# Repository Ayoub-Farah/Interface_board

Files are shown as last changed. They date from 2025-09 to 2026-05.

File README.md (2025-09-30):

# Obsidian

## Description

Obsidian is a FPGA carrier board in development, designed to interface with ADC and DAC devices,
either stand-alone or as an I/O expansion board for [Marble](https://github.com/BerkeleyLab/Marble).

The design files here were created with [KiCad](https://www.kicad.org/) version 9.0.0-rc3.

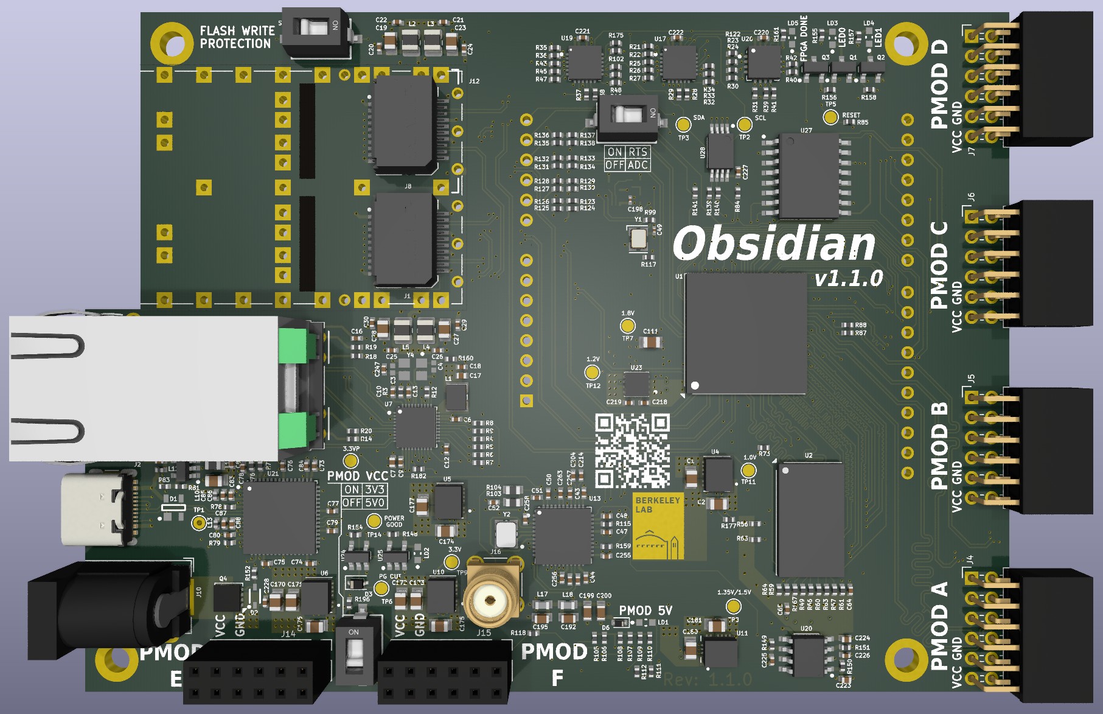
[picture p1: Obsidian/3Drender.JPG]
Obsidian


## Major Parts

- Xilinx XC7A50T-1CSG325C FPGA

## Credits

## License

---

## Project status

### Included features

- [ ] Arduino shield compatible, like the Digilent Arty
- [ ] SPI flash boot
- [ ] DDR3 memory chip
- [ ] FTDI USB interface
- [ ] 2 direct LEDs
- [ ] 1 GigE port (PoE?)
- [ ] 6 Pmod ports (3.3V)
- [ ] MS5351M or SI5351A or similar for GTP frequency reference
- [ ] USB-C (single USB cable)
- [ ] 4 x SFP
- [ ] I2C or 1-Wire chip for serial number / ROM
- [ ] White Rabbit compatibility

### High speed links

The 7A50T-1CSG325C has 4 x GTP lanes, capable of 3.75 Gbaud.
The primary use-case involves attaching one of those to a Marble over fiber.

The two MGTREFCLK signals are the direct White-Rabbit 125 MHz TCVCXO
and the configurable MS5351M output.

### Wishlist

- [ ] Standardized board size for good case options: Mini-ATX (150 x 150 mm)? Pico-ATX?

### User I/O Pins
- 48 pins for 6 x Pmod
- 49 pins for DDR3 (equivalent to Arty and Marble-Mini)
- 13 pins for RGMII (including reset pin)
- 2 Ethernet PHY MDIO
- 4 pins for White Rabbit DAC (can attach LEDs to 2 x SYNC pins?)
- 1 or more clock input (not counting MGTREFCLK)
- 2 pins for I2C
- 14 pins for Arduino digital IO
- 8 pins for Arduino 4 analog channels
- 2 pins USB UART
- 3 pins SPI flash boot (not counting CCLK in bank 0)

total 146 so far, out of 150 possible with 7A50T-1CSG325C

## Copyright

Obsidian A35 Copyright (c) 2025, The Regents of the University of California, through Lawrence Berkeley National Laboratory (subject to receipt of any required approvals from the U.S. Department of Energy). All rights reserved.

This documentation describes Obsidian A35 and is licensed under the CERN Open Hardware License v 2.0 - Permissive.

NOTICE. This documentation was developed under funding from the U.S. Department of Energy and the U.S. Government consequently retains certain rights. As such, the U.S. Government has been granted for itself and others acting on its behalf a paid-up, nonexclusive, irrevocable, worldwide license in the documentation to reproduce, distribute copies to the public, prepare derivative works, and perform publicly and display publicly, and to permit others to do so.

You may redistribute and modify this documentation under the terms of the CERN OHL v. 2.0 - Permissive (see [CERN-OHL-P-2.0](https://spdx.org/licenses/CERN-OHL-P-2.0.html) for terms and conditions). THIS DOCUMENTATION IS PROVIDED BY THE COPYRIGHT HOLDERS AND CONTRIBUTORS "AS IS" AND ANY EXPRESS OR IMPLIED WARRANTIES, INCLUDING, BUT NOT LIMITED TO, THE IMPLIED WARRANTIES OF MERCHANTABILITY AND FITNESS FOR A PARTICULAR PURPOSE ARE DISCLAIMED. IN NO EVENT SHALL THE COPYRIGHT OWNER OR CONTRIBUTORS BE LIABLE FOR ANY DIRECT, INDIRECT, INCIDENTAL, SPECIAL, EXEMPLARY, OR CONSEQUENTIAL DAMAGES (INCLUDING, BUT NOT LIMITED TO, PROCUREMENT OF SUBSTITUTE GOODS OR SERVICES; LOSS OF USE, DATA, OR PROFITS; OR BUSINESS INTERRUPTION) HOWEVER CAUSED AND ON ANY THEORY OF LIABILITY, WHETHER IN CONTRACT, STRICT LIABILITY, OR TORT (INCLUDING NEGLIGENCE OR OTHERWISE) ARISING IN ANY WAY OUT OF THE USE OF THIS SOFTWARE, EVEN IF ADVISED OF THE POSSIBILITY OF SUCH DAMAGE. Please see the CERN OHL v. 2.0 for applicable conditions.

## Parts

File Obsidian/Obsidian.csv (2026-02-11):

Id | Designator | Footprint | Quantity | Designation | Supplier and ref
1 | R156,R76,R155,R158,R81,R176,R148,R161,R157,R77,R163,R2,R98,R75 | RESC1005X40N | 14 | R0402_10K_1%_0.0625W_100PPM
2 | C13,C227,C78,C84,C10,C22,C247,C202,C74,C80,C205,C221,C225,C26,C29,C9,C88,C222,C77,C248,C86,C12,C228,C76,C226,C204,C82,C220,C75,C24,C214,C25,C21,C18,C16,C30,C79,C20,C64,C65,C6,C213,C32,C63,C34,C66,C68,C14,C40,C42,C33,C15,C31,C8,C70,C67,C41,C69,C39 | CAPC1005X55N | 59 | CC0402_100NF_50V_10%_X7R
3 | R61,R167,R63,R65,R66,R56,R64,R60,R159,R59,R49,R57,R55,R58,R54,R53,R70,R69,R71,R52,R50,R62,R67,R68,R51,R153 | RESC1005X40N | 26 | R0402_40R2_1%_0.0625W_100PPM
4 | U3 | MSOP-10_3x3mm_P0.5mm | 1 | Si5351A-B-GT
5 | R129,R137,R133,R123 | RESC1005X40N | 4 | R0402_140R_1%_0.0625W_100PPM
6 | R131,R135,R125,R127 | RESC1005X40N | 4 | R0402_2K32_1%_0.0625W_100PPM
7 | U12 | SOT95P284X122-5N | 1 | LP5951MF-3.0/NOPB
8 | C19,C177,C172,C181,C1,C28,C23,C171,C27,C170,C173,C83,C38,C36,C35,C37 | CAPC2012X135N | 16 | CC0805_22UF_16V_10%_X5R
9 | TP2,TP12,TP10,TP5,TP11,TP9,TP8,TP6,TP3,TP14,TP7,TP13,TP4 | TestPoint_Pad_D1.5mm | 13 | TestPoint
10 | R182,R28,R34,R87,R25,R32,R31,R45,R122,R44,R14,R41,R140,R85,R47,R21,R79,R18,R73,R26,R24,R30,R12,R38,R43,R39,R46,R48,R22,R37,R141,R33,R139,R35,R23,R29,R36,R40,R42,R27,R11,R15,R16,R13,R10,R86,R17 | RESC1005X40N | 47 | R0402_4K7_1%_0.0625W_100PPM
11 | R19,R20 | RESC1005X40N | 2 | R0402_330R_1%_0.0625W_100PPM
12 | U16 | QFN50P500X500X100-33N-S355 | 1 | CDCM61004RHB
13 | C209,C191,C208,C198,C185,C196,C194,C189,C212,C183,C210,C215,C190,C206,C197,C211,C165,C249,C154,C250,C166,C164,C159,C186,C169,C158,C163,C157,C160 | CAPC0603X33N | 29 | CC0201_100NF_6.3V_10%_X5R
14 | L17,L18,L20 | INDC1608X65N | 3 | IND0603_MURATA_BLM18SG121TN1D
15 | C199,C201,C192,C200,C203,C195,C187 | CAPC1709X100N | 7 | CC0603_22UF_6.3V_20%_X5R
16 | C188 | CAPC1005X55N | 1 | CC0201_100NF_6.3V_10%_X5R
17 | J6,J4,J5,J7 | PinSocket_2x06_P2.54mm_Horizontal_PMOD | 4 | Conn_02x06_Top_Bottom
18 | C218,C85,C87,C73,C81,C219,C103,C108,C168,C123,C131,C118,C105,C167,C161,C107,C142,C104,C106,C133,C162,C61,C156,C132,C141,C117 | CAPC1005X55N | 26 | CC0402_4.7UF_16V_20%_X5R
19 | R113,R116 | RESC1005X40N | 2 | R0402_510R_0.1%_0.0625W_10PPM
20 | L3,L5,L2,L4,L8,L9,L6,L7 | L_1008_2520Metric | 8 | 4.7 uH
21 | R150,R132,R136,R151,R84,R89,R128,R126,R149,R88,R90 | RESC1005X40N | 11 | R0402_1K_1%_0.0625W_100PPM
22 | U18 | SOT-23-5 | 1 | TLV77325PDBVR
23 | U11,U4,U10,U5,U6 | VREG_TPSM863257RDXR | 5 | TPSM863257RDXR
24 | C3,C4,C72,C71 | CAPC1005X55N | 4 | CC0402_27PF_50V_5%_C0G
25 | R175,R154,R174,R173,R171,R165,R170,R172,R164,R166 | RESC1005X40N | 10 | R0402_100K_1%_0.0625W_100PPM
26 | U19,U17 | QFN50P400X400X80-25N-S245 | 2 | TCA9535RTWR
27 | Q2,Q3,Q1 | SOT95P240X110-3N | 3 | BSS138LT1G
28 | Y2 | OSCCC320X500X160-4N | 1 | VM53S3-25.000-2.5/-30+75
29 | R147,R162,R146,R145,R144,R95,R97,R92,R100,R142,R93,R96,R143,R101 | RESC1005X40N | 14 | R0402_30K_1%_0.0625W_100PPM
30 | C2,C174,C176,C180,C175 | CAPC2012X95N | 5 | CC0805_10UF_25V_10%_X5R
31 | R102,R121,R99,R103,R120,R72 | RESC1005X40N | 6 | R0402_240R_1%_0.0625W_100PPM
32 | C193 | CAPC1005X55N | 1 | CC0402_2.2NF_50V_10%_X7R
33 | R8,R4,R6,R7,R9,R5 | RESC1005X40N | 6 | R0402_22R_1%_0.0625W_100PPM
34 | R124,R134,R138,R130 | RESC1005X40N | 4 | R0402_845R_0.1%_0.063W_25PPM
35 | C207,C182,C184,C216,C217 | CAPC1005X55N | 5 | CC0402_1UF_16V_10%_X5R
36 | J2 | USB_C_Receptacle_GCT_USB4105-xx-A_16P_TopMnt_Horizontal | 1 | USB_C_Receptacle_USB2.0_16P
37 | D1 | SOT190P230X110-4N | 1 | PRTR5V0U2X
38 | R78,R152,R177,R180,R178,R169,R179,R181 | RESC1005X40N | 8 | R0402_12K_1%_0.0625W_100PPM
39 | B3,B1,B4,B2 | MTG320_550 | 4 | PLATED_HOLE3.2_PAD5.5
40 | R105,R106,R110,R160,R104,R107,R112,R108,R111,R109 | RESC1005X40N | 10 | R0402_0R_JUMPER
41 | C7,C17,C223,C224,C5,C151,C152,C62,C11 | CAPC1005X70N | 9 | CC0402_10UF_6.3V_20%_X5R
42 | Y6 | XTAL_TXC_8Y | 1 | XTAL_25MHZ_TXC_8Y-25.000MAAJ-T
43 | C111,C122,C119,C110,C109 | CAPC2012X145N | 5 | CC0805_100UF_6.3V_20%_X5R
44 | U25,U24 | SOT95P280X145-5N | 2 | SN74LVC1G07DBV
45 | LD1 | LED_OSRAM_LS Q976 | 1 | LED_OSRAM_LS_Q976-NR-1
46 | U21 | QFN50P900X900X100-65N-S445 | 1 | FT2232HQ
47 | R118,R119 | RESC1005X40N | 2 | R0402_200R_1%_0.0625W_100PPM
48 | R83,R74 | RESC1005X40N | 2 | R0402_2K2_1%_0.0625W_100PPM
49 | D2 | SODFL2513X100N | 1 | MM3Z12VB
50 | SW2,SW1 | SW_OMRON_A6SN-1101 | 2 | SW_DIP_x01
51 | U28 | SOP65P640X120-8N | 1 | 24AA256UID-I_ST
52 | J14,J15 | PinSocket_2x06_P2.54mm_Vertical_PMOD | 2 | Conn_02x06_Top_Bottom
53 | R82,R80 | RESC1005X40N | 2 | R0402_5K1_1%_0.0625W_100PPM
54 | J8,J9 | TE_2180739-1 | 2 | 2180739-1
55 | U8 | SOT95P280X145-5N | 1 | TLV62565DBV
56 | Q4 | Diodes_PowerDI3333-8 | 1 | DMP3013SFV
57 | R117,R115,R114 | RESC1005X40N | 3 | R0402_100R_1%_0.1W_100PPM
58 | U14,U15 | SOP65P490X110-8N | 2 | DAC8550IDGK
59 | J1,J11 | TYCO_1367073-1 | 2 | TYCO_1888247-1
60 | Y3 | OSC_IQD_CFPV-45 | 1 | OSC_20MHZ_IQD_LFVCXO026156
61 | U26 | QFN65P400X400X100-17N-S225 | 1 | PCA9546ARGV
62 | U2 | FBGA-96_8x14mm_Layout9x16_P0.8mm | 1 | MT41K512M16HA-125_E / MT41K512M16VRP-107 IT:P
63 | U13 | SOIC127P600X175-8N | 1 | LM336M-2.5
64 | L10,L13,L12 | INDC1005X55N | 3 | IND0402_MURATA_BLM15PX121SN1D
65 | LD2,LD3,LD5,LD4 | LED_KINGBRIGHT_KPH-1608CGCK | 4 | LED_KINGBRIGHT_KPH-1608CGCK
66 | L14 | IND_WURTH_WE-PMCI_0806LR | 1 | IND_2.2UH_20%_WURTH_WE-PMCI_74479276222C
67 | J3 | BEL_0826-1G1T-43-F | 1 | BELFUSE_0826-1G1T-43-F
68 | U23 | SON65P300X300X100-9N-R170X245 | 1 | NCV59801CML120TCG
69 | D3 | D_SOD-323 | 1 | BAS316
70 | U1 | Xilinx_CSG325 | 1 | XC7A35T-CSG325
71 | A1 | Arduino_UNO_R3 | 1 | Arduino_UNO_R3
72 | Y4 | XTAL_EPSON_TSX-3225 | 1 | XTAL_25MHZ_EPSON_TSX-3225_25.0000MF10Z-AC
73 | U27 | SOIC127P1030X265-16N | 1 | S25FL128SAGMFI001
74 | U20 | SOIC127P600X168-9N-S230 | 1 | RT9045AGSP / AP2303
75 | L1 | IND_BOURNS_SRP3212 | 1 | IND_2.2UH_20%_BOURNS_SRP3212
76 | U7 | QFN40P500X500X80-41N-S360 | 1 | RTL8211F-CG
77 | R3 | RESC1005X40N | 1 | R0402_2K49_1%_0.063W_100PPM
78 | TP1 | TestPoint_THTPad_D1.5mm_Drill0.7mm | 1 | TestPoint
79 | J10 | BarrelJack_GCT_DCJ200-10-A_Horizontal | 1 | Barrel_Jack_Switch
80 | J12,J13 | TYCO_1888247-1 | 2 | TYCO_1888247-1
81 | C95,C126,C245,C94,C92,C153,C120,C90,C144,C137,C134,C124,C145,C115,C143,C89,C96,C136,C146,C91,C246,C125,C135,C113,C93,C155,C116,C114,C127 | CAPC0603X33N | 29 | CC0201_470NF_4V_20%_X5R
82 | C240,C244,C121,C139,C230,C100,C128,C236,C239,C235,C130,C138,C232,C148,C242,C238,C147,C149,C233,C129,C99,C229,C97,C243,C98,C231,C102,C237,C241,C101,C140,C112,C150,C234 | CAPC0603X33N | 34 | CC0201_47NF_6.3V_10%_X5R
83 | L16 | INDC1005X55N | 1 | IND0402_MURATA_BLM15HB221SN1
84 | R1 | RESC1608X55N | 1 | R0603_6K65_0.1%_0.063W_10PPM
85 | L15 | INDC2013X145N | 1 | IND0805_TDK_MLZ2012M150WT000
86 | U22 | SOIC127P600X175-8N | 1 | 93C46B-I_SN
87 | U9 | SOT-23 | 1 | REF3012
88 | C179,C178 | CAPC1005X55N | 2 | CC0402_22PF_50V_5%_C0G
89 | R168 | RESC1005X40N | 1 | R0402_80R6_1%_0.1W_100PPM
90 | R91,R94 | RESC2012X60N | 2 | R0805_135K_0.1%_0.1W_25PPM_KOA_RN73R2ATTD1353B25
91 | Y5 | XTAL_TXC_7A | 1 | XTAL_12MHZ_TXC_7A-12.000MAAJ-T
92 | L11 | INDC1608X95N | 1 | IND0603_MURATA_BLM18AG601SN1
93 | Y1 | OSC_ABRACON_ASEMPC | 1 | OSC_25MHZ_RAKON_IVT3205CR

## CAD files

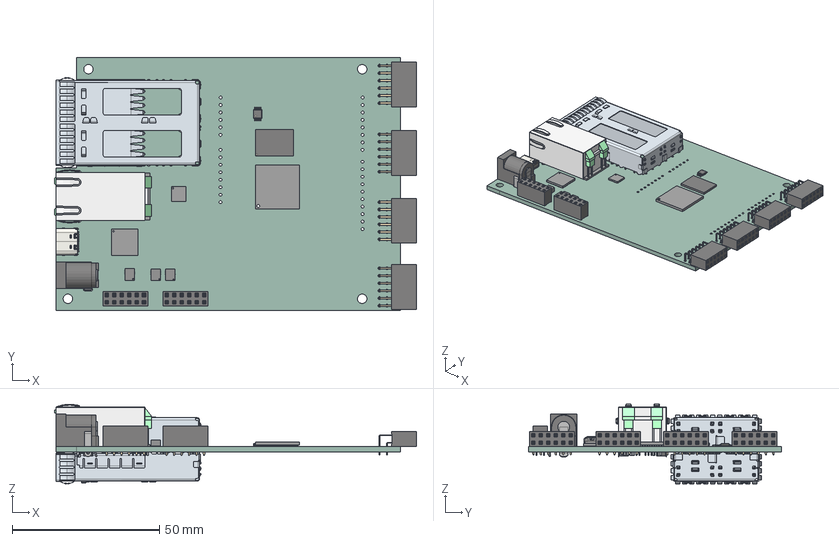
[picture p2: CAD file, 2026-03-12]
Obsidian/Obsidian.step
123.0 x 86.0 x 27.0 mm
MSOP-10_3x3mm_P0.5mm
PinSocket_2x06_P2.54mm_Horizontal x 4
USB_C_Receptacle_GCT_USB4105-xx-A_16P_TopMnt_Horizontal
QFN50P900X900X100-65N-S445
kicad_embedded_953FA939E6CC6517DF7ED2E297E245B9 x 3
PinSocket_2x06_P2.54mm_Vertical x 2
kicad_embedded_1A2E63AEB301535E0CE7C40C940B3B74 x 2
BGA-96_9.0x13.0mm_Layout2x3x16_P0.8mm
BGA324C80P18X18_1500X1500X150
QFN40P500X500X80-41N-S360
BarrelJack_GCT_DCJ200-10-A_Horizontal x 2
Marble_Tiny_PCB

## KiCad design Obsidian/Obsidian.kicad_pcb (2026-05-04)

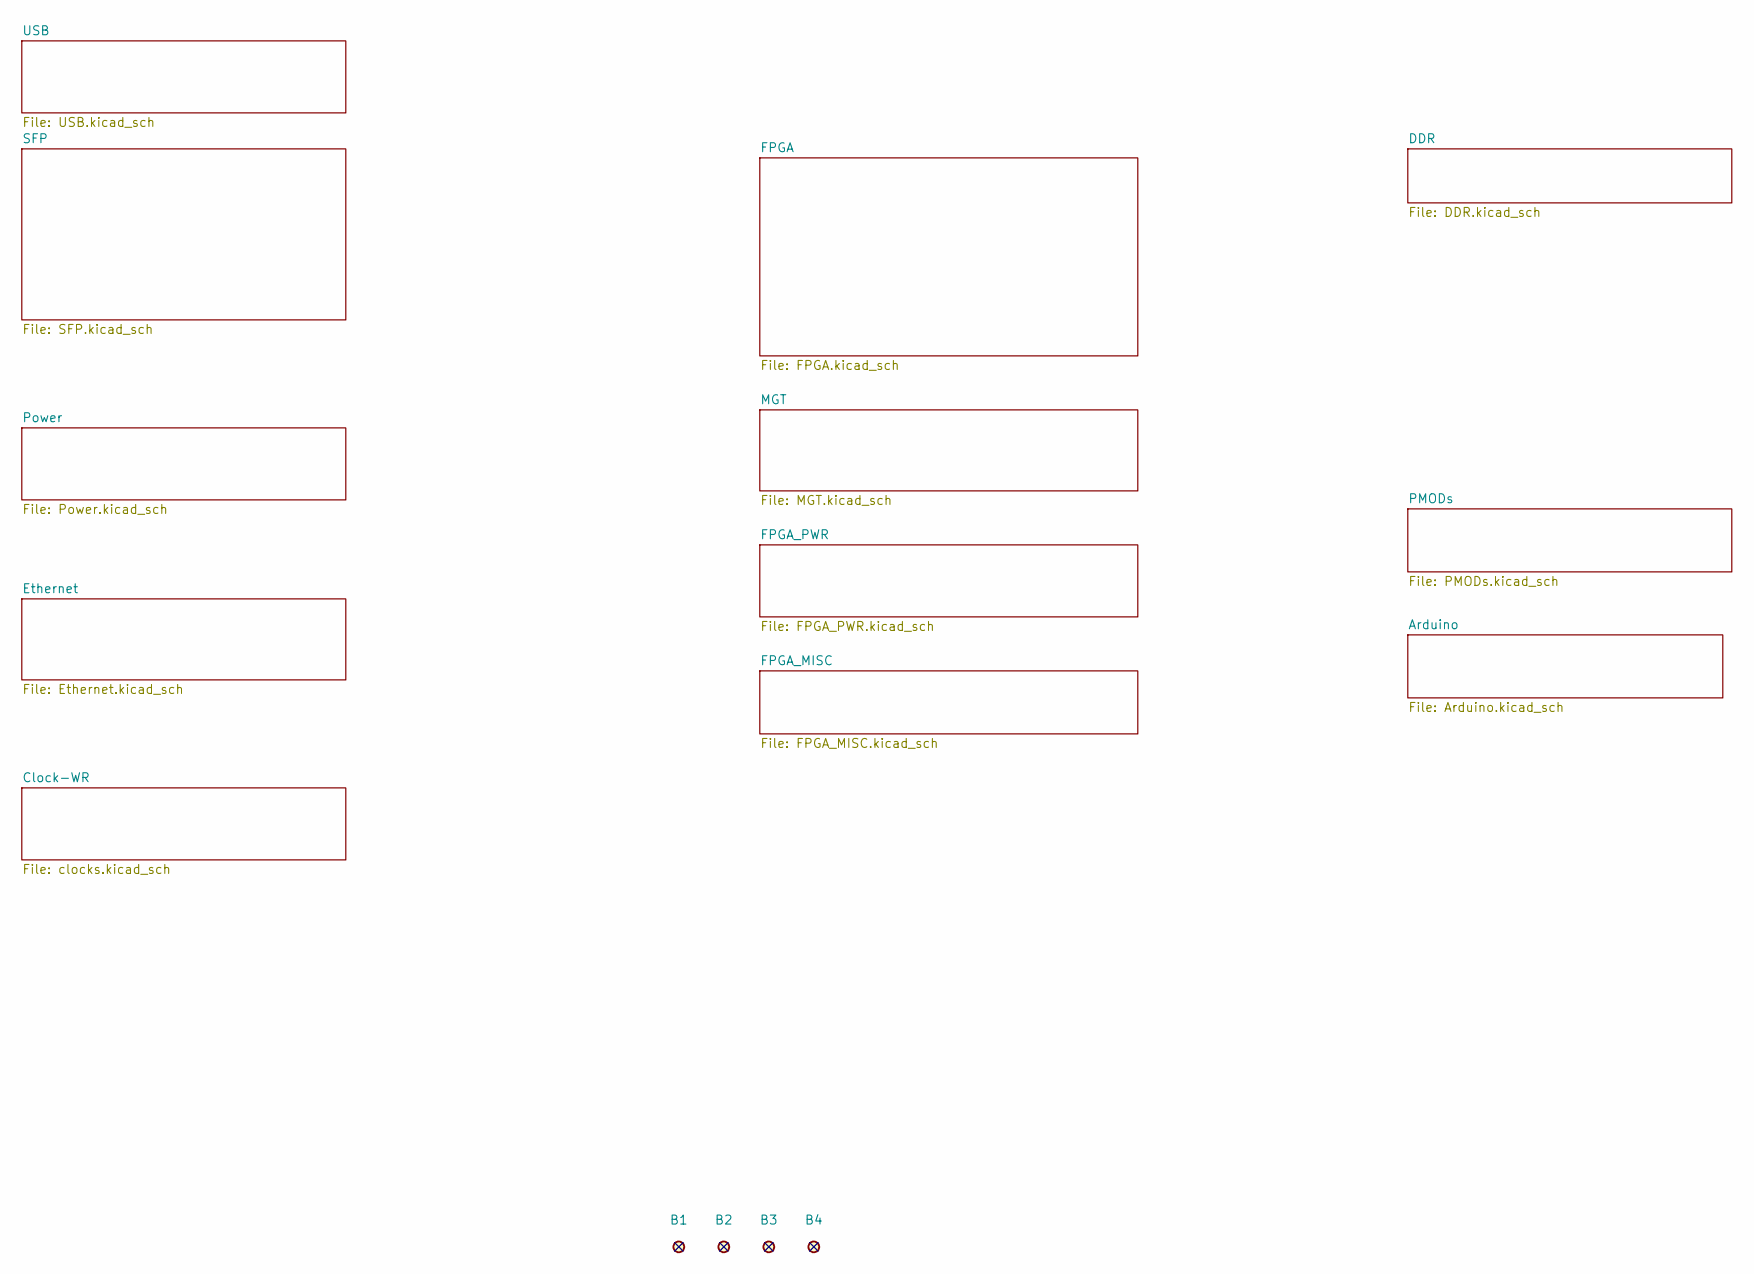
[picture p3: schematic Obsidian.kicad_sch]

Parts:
B1, B2, B3, B4: PLATED_HOLE3.2_PAD5.5; MTG320_550; Part Number PLATED_HOLE3.2_PAD5.5

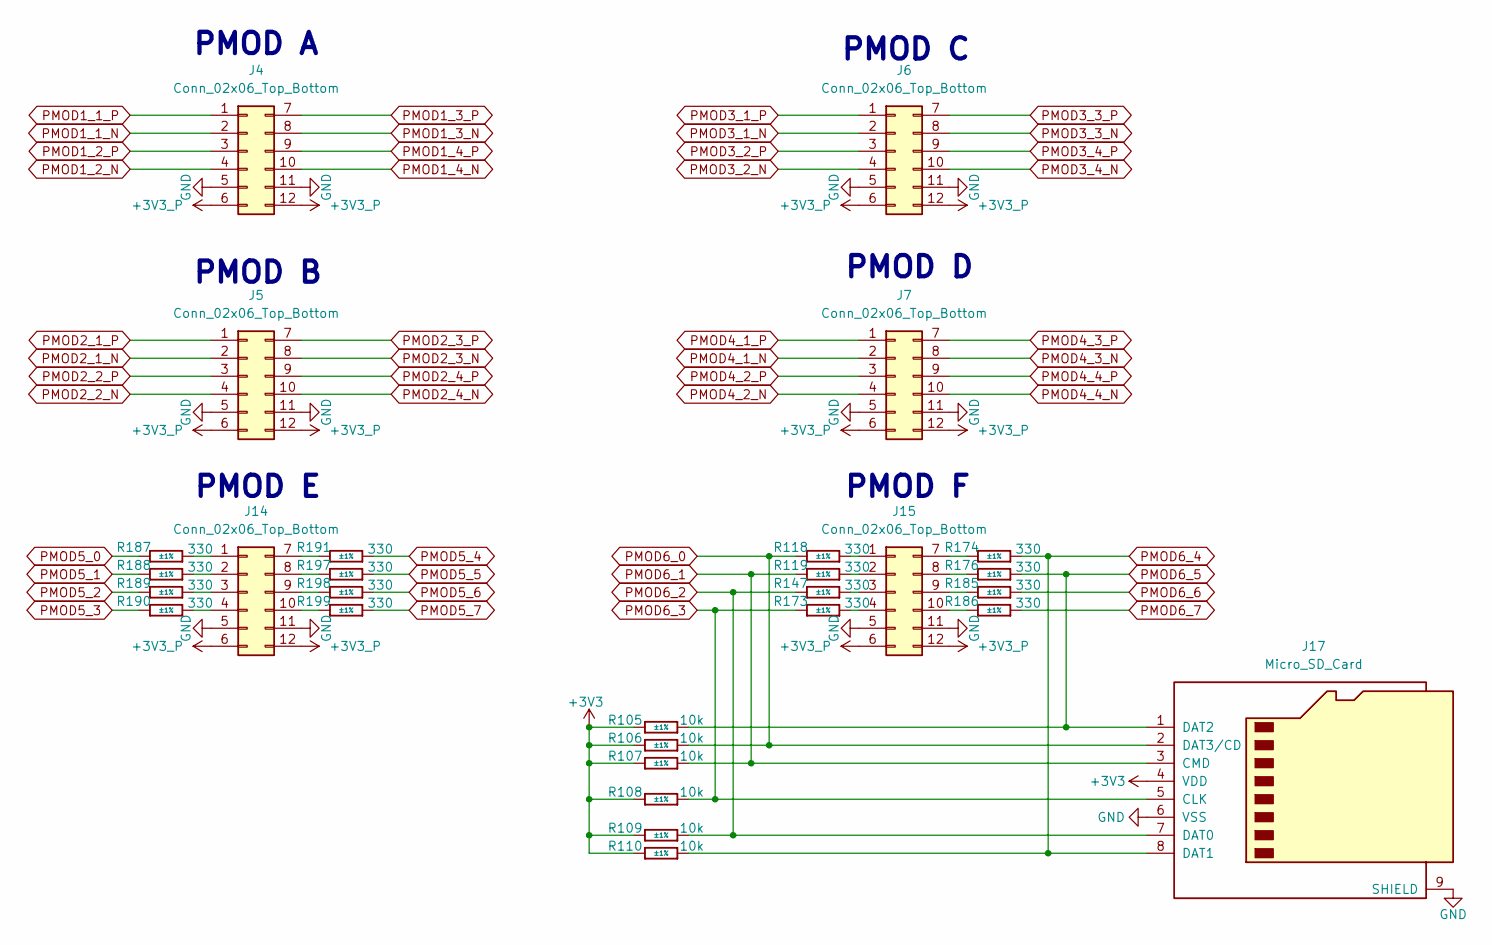
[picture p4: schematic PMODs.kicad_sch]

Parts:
J4, J5, J6, J7: Conn_02x06_Top_Bottom; PinSocket_2x06_P2.54mm_Horizontal_PMOD
J14, J15: Conn_02x06_Top_Bottom; PinSocket_2x06_P2.54mm_Vertical_PMOD
J17: Micro_SD_Card; microSD_HC_Molex_47219-2001
R105, R106, R107, R108, R109, R110: R0402_10K_1%_0.0625W_100PPM; RESC1005X40N; Tolerance ±1%; Part Number R0402_10K_1%_0.0625W_100PPM
R118, R119, R147, R173, R174, R176, R185, R186, R187, R188, R189, R190, R191, R197, R198, R199: R0402_330R_1%_0.0625W_100PPM; RESC1005X40N; Tolerance ±1%; Part Number R0402_330R_1%_0.0625W_100PPM

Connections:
+3V3: J17.4 (VDD), R105.1, R106.1, R107.1, R108.1, R109.1, R110.1; also elsewhere on the board
+3V3_P: J4.6, J4.12, J5.6, J5.12, J6.6, J6.12, J7.6, J7.12, J14.6, J14.12, J15.6, J15.12; also elsewhere on the board
GND: J4.5, J4.11, J5.5, J5.11, J6.5, J6.11, J7.5, J7.11, J14.5, J14.11, J15.5, J15.11, J17.6 (VSS), J17.9 (SHIELD); also elsewhere on the board
unnamed: J14.1, R187.2
unnamed: J14.2, R188.2
unnamed: J14.3, R189.2
unnamed: J14.4, R190.2
unnamed: J14.7, R191.1
unnamed: J14.8, R197.1
unnamed: J14.9, R198.1
unnamed: J14.10, R199.1
unnamed: J15.1, R118.2
unnamed: J15.2, R119.2
unnamed: J15.3, R147.2
unnamed: J15.4, R173.2
unnamed: J15.7, R174.1
unnamed: J15.8, R176.1
unnamed: J15.9, R185.1
unnamed: J15.10, R186.1
PMOD1_1_N: J4.2; also elsewhere on the board
PMOD1_1_P: J4.1; also elsewhere on the board
PMOD1_2_N: J4.4; also elsewhere on the board
PMOD1_2_P: J4.3; also elsewhere on the board
PMOD1_3_N: J4.8; also elsewhere on the board
PMOD1_3_P: J4.7; also elsewhere on the board
PMOD1_4_N: J4.10; also elsewhere on the board
PMOD1_4_P: J4.9; also elsewhere on the board
PMOD2_1_N: J5.2; also elsewhere on the board
PMOD2_1_P: J5.1; also elsewhere on the board
PMOD2_2_N: J5.4; also elsewhere on the board
PMOD2_2_P: J5.3; also elsewhere on the board
PMOD2_3_N: J5.8; also elsewhere on the board
PMOD2_3_P: J5.7; also elsewhere on the board
PMOD2_4_N: J5.10; also elsewhere on the board
PMOD2_4_P: J5.9; also elsewhere on the board
PMOD3_1_N: J6.2; also elsewhere on the board
PMOD3_1_P: J6.1; also elsewhere on the board
PMOD3_2_N: J6.4; also elsewhere on the board
PMOD3_2_P: J6.3; also elsewhere on the board
PMOD3_3_N: J6.8; also elsewhere on the board
PMOD3_3_P: J6.7; also elsewhere on the board
PMOD3_4_N: J6.10; also elsewhere on the board
PMOD3_4_P: J6.9; also elsewhere on the board
PMOD4_1_N: J7.2; also elsewhere on the board
PMOD4_1_P: J7.1; also elsewhere on the board
PMOD4_2_N: J7.4; also elsewhere on the board
PMOD4_2_P: J7.3; also elsewhere on the board
PMOD4_3_N: J7.8; also elsewhere on the board
PMOD4_3_P: J7.7; also elsewhere on the board
PMOD4_4_N: J7.10; also elsewhere on the board
PMOD4_4_P: J7.9; also elsewhere on the board
PMOD5_0: R187.1; also elsewhere on the board
PMOD5_1: R188.1; also elsewhere on the board
PMOD5_2: R189.1; also elsewhere on the board
PMOD5_3: R190.1; also elsewhere on the board
PMOD5_4: R191.2; also elsewhere on the board
PMOD5_5: R197.2; also elsewhere on the board
PMOD5_6: R198.2; also elsewhere on the board
PMOD5_7: R199.2; also elsewhere on the board
PMOD6_0: J17.2 (DAT3/CD), R106.2, R118.1; also elsewhere on the board
PMOD6_1: J17.3 (CMD), R107.2, R119.1; also elsewhere on the board
PMOD6_2: J17.7 (DAT0), R109.2, R147.1; also elsewhere on the board
PMOD6_3: J17.5 (CLK), R108.2, R173.1; also elsewhere on the board
PMOD6_4: J17.8 (DAT1), R110.2, R174.2; also elsewhere on the board
PMOD6_5: J17.1 (DAT2), R105.2, R176.2; also elsewhere on the board
PMOD6_6: R185.2; also elsewhere on the board
PMOD6_7: R186.2; also elsewhere on the board

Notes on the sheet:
PMOD F
PMOD E
PMOD C
PMOD A
PMOD B
PMOD D

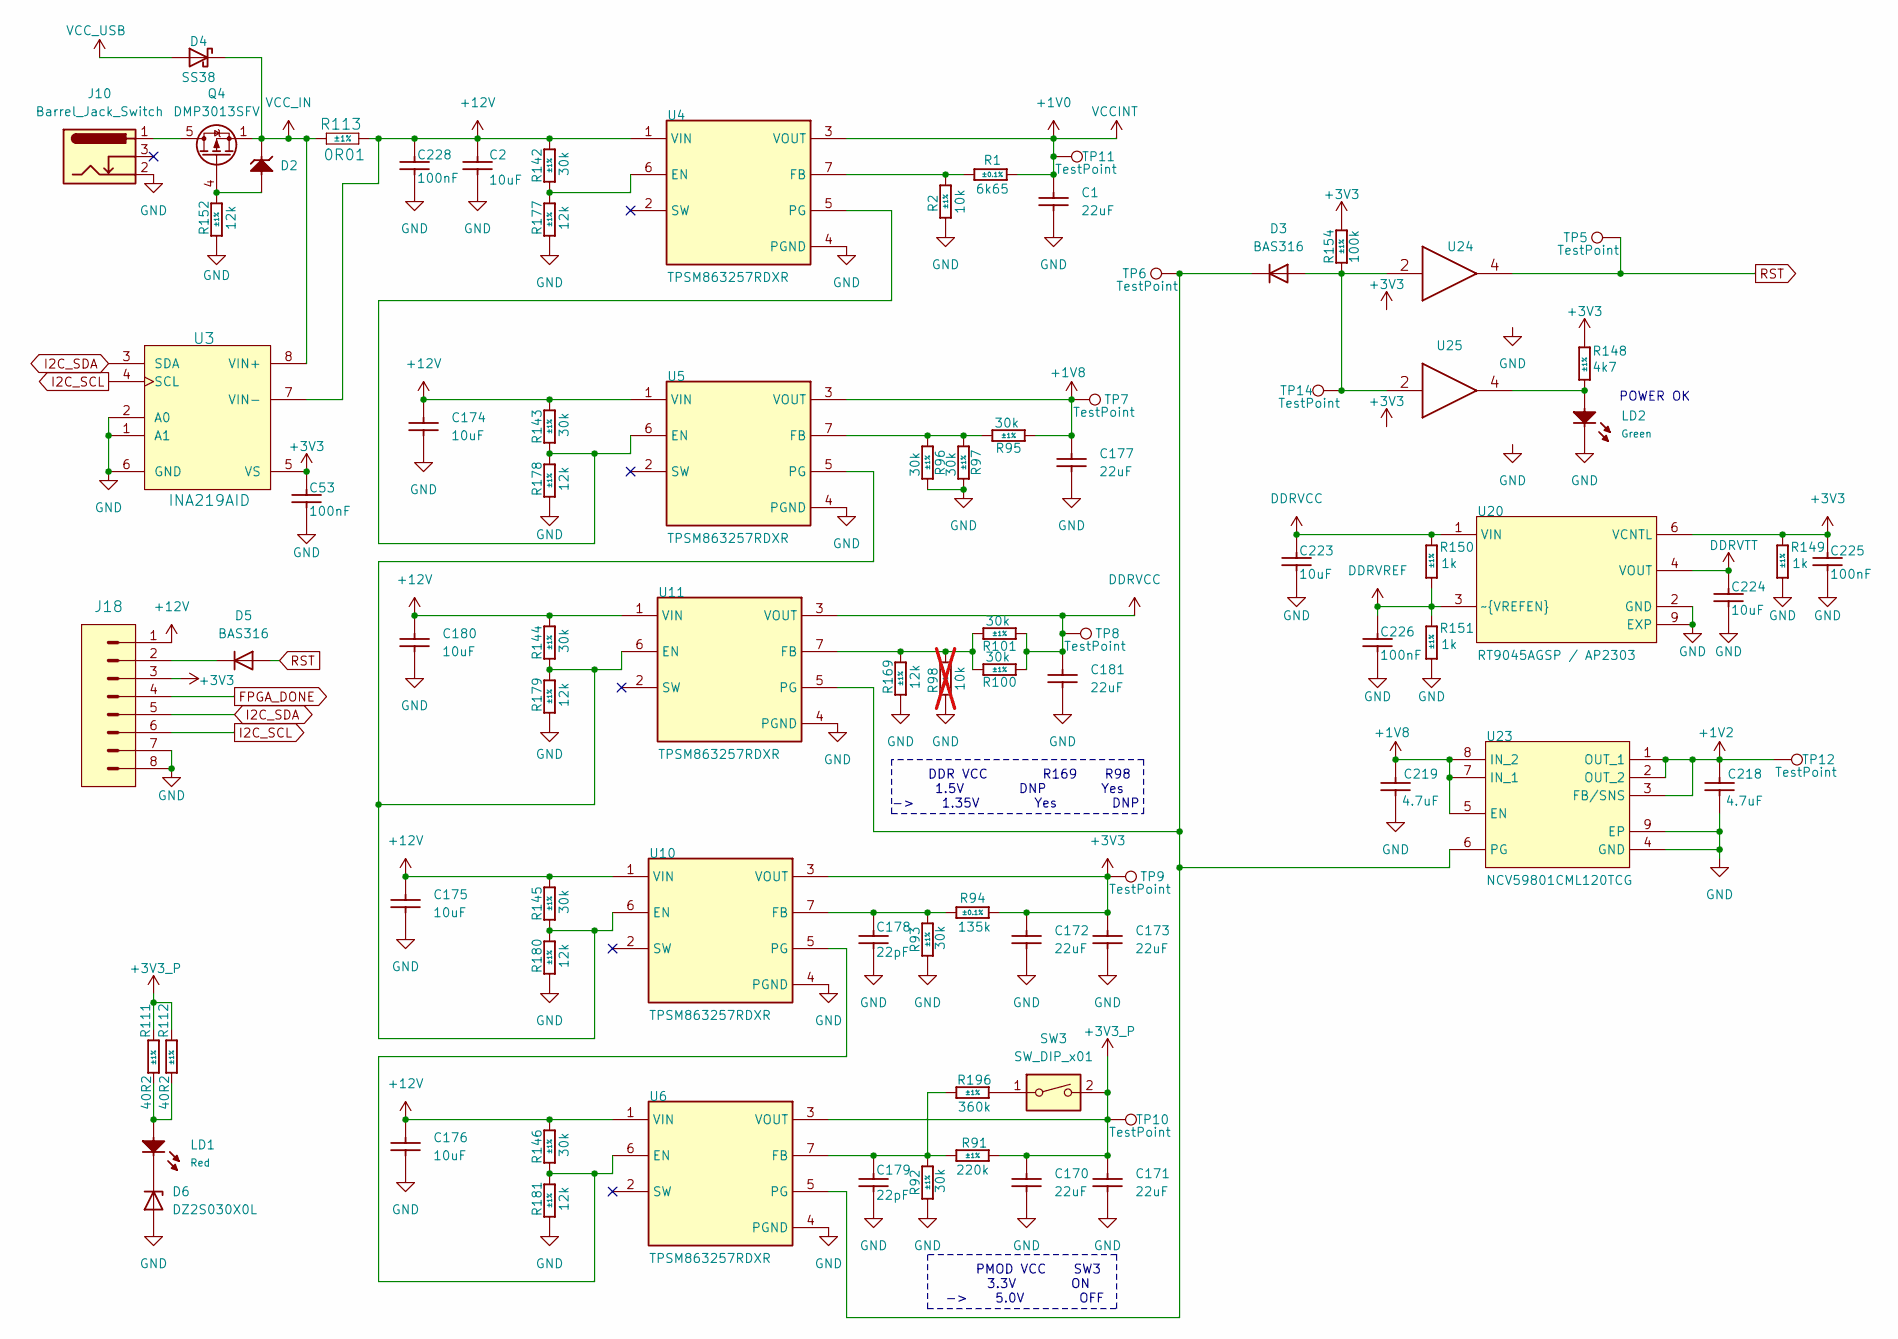
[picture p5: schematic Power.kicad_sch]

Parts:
C1, C170, C171, C172, C173, C177, C181: CC0805_22UF_16V_10%_X5R; CAPC2012X135N; Voltage 16V; Tolerance ±10%; Part Number CC0805_22UF_16V_10%_X5R
C2, C174, C175, C176, C180: CC0805_10UF_25V_10%_X5R; CAPC2012X95N; Voltage 25V; Tolerance ±10%; Part Number CC0805_10UF_25V_10%_X5R
C53, C225, C226, C228: CC0402_100NF_50V_10%_X7R; CAPC1005X55N; Voltage 50V; Tolerance ±10%; Part Number CC0402_100NF_50V_10%_X7R
C178, C179: CC0402_22PF_50V_5%_C0G; CAPC1005X55N; Voltage 50V; Tolerance ±5%; Part Number CC0402_22PF_50V_5%_C0G
C218, C219: CC0402_4.7UF_16V_20%_X5R; CAPC1005X55N; Voltage 16V; Tolerance ±20%; Part Number CC0402_4.7UF_16V_20%_X5R
C223, C224: CC0402_10UF_6.3V_20%_X5R; CAPC1005X70N; Voltage 6.3V; Tolerance ±10%; Part Number CC0402_10UF_6.3V_20%_X5R
D2: MM3Z12VB; SODFL2513X100N; Voltage 12V; Part Number MM3Z12VB
D3, D5: BAS316; D_SOD-323
D4: SS38; D_SMA
D6: DZ2S030X0L; D_SOD-523
J10: Barrel_Jack_Switch; BarrelJack_GCT_DCJ200-10-A_Horizontal
J18: Header 8; WURTH_61300821121; Part Number WURTH_61300821121
LD1, LD2: LED_KINGBRIGHT_KPH-1608CGCK; Part Number LED_KINGBRIGHT_KPH-1608CGCK
Q4: DMP3013SFV; Diodes_PowerDI3333-8
R1: R0603_6K65_0.1%_0.063W_10PPM; RESC1608X55N; Tolerance ±0.1%; Part Number R0603_6K65_0.1%_0.063W_10PPM
R2: R0402_10K_1%_0.0625W_100PPM; RESC1005X40N; Tolerance ±1%; Part Number R0402_10K_1%_0.0625W_100PPM
R91: R0402_220K_1%_0.0625W_100PPM; RESC1005X40N; Tolerance ±1%; Part Number R0402_220K_1%_0.0625W_100PPM
R92, R93, R95, R96, R97, R100, R101, R142, R143, R144, R145, R146: R0402_30K_1%_0.0625W_100PPM; RESC1005X40N; Tolerance ±1%; Part Number R0402_30K_1%_0.0625W_100PPM
R94: R0805_135K_0.1%_0.1W_25PPM_KOA_RN73R2ATTD1353B25; RESC2012X60N; Tolerance ±0.1%; Part Number R0805_135K_0.1%_0.1W_25PPM_KOA_RN73R2AT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
R98: R0402_10K_1%_0.0625W_100PPM; RESC1005X40N; Tolerance ±1%; Part Number R0402_10K_1%_0.0625W_100PPM; not fitted
R111, R112: R0402_40R2_1%_0.0625W_100PPM; RESC1005X40N; Tolerance ±1%; Part Number R0402_40R2_1%_0.0625W_100PPM
R113: 0R01; RESC3216X65N; Tolerance ±1%; Part Number R1206_0R01_1%_1W_100PPM
R148: R0402_4K7_1%_0.0625W_100PPM; RESC1005X40N; Tolerance ±1%; Part Number R0402_4K7_1%_0.0625W_100PPM
R149, R150, R151: R0402_1K_1%_0.0625W_100PPM; RESC1005X40N; Tolerance ±1%; Part Number R0402_1K_1%_0.0625W_100PPM
R152, R169, R177, R178, R179, R180, R181: R0402_12K_1%_0.0625W_100PPM; RESC1005X40N; Tolerance ±1%; Part Number R0402_12K_1%_0.0625W_100PPM
R154: R0402_100K_1%_0.0625W_100PPM; RESC1005X40N; Tolerance ±1%; Part Number R0402_100K_1%_0.0625W_100PPM
R196: R0402_360K_1%_0.0625W_100PPM; RESC1005X40N; Tolerance ±1%; Part Number R0402_360K_1%_0.0625W_100PPM
SW3: SW_DIP_x01; SW_OMRON_A6SN-1101
TP5, TP6, TP7, TP8, TP9, TP10, TP11, TP12, TP14: TestPoint; TestPoint_Pad_D1.5mm
U3: INA219AID; SOIC127P600X175-8N; Part Number INA219AID
U4, U5, U6, U10, U11: TPSM863257RDXR; VREG_TPSM863257RDXR
U20: RT9045AGSP / AP2303; SOIC127P600X168-9N-S230
U23: NCV59801CML120TCG; SON65P300X300X100-9N-R170X245; MANUFACTURER_PART_NUMBER NCV59801CML120TCG; MOUSER PART NUMBER *
U24, U25: SN74LVC1G07DBV; SOT95P280X145-5N; Part Number SN74LVC1G07DBV

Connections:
+1V0: C1.2, R1.2, TP11.1, U4.3 (VOUT); also elsewhere on the board
+1V2: C218.2, TP12.1, U23.1 (OUT_1), U23.2 (OUT_2), U23.3 (FB/SNS); also elsewhere on the board
+1V8: C177.2, C219.2, R95.2, TP7.1, U5.3 (VOUT), U23.5 (EN), U23.7 (IN_1), U23.8 (IN_2); also elsewhere on the board
+3V3: C53.2, C172.2, C173.2, C225.2, J18.3, R94.1, R148.2, R149.2, R154.1, TP9.1, U3.5 (VS), U10.3 (VOUT), U20.6 (VCNTL), U24.5 (VCC), U25.5 (VCC); also elsewhere on the board
+3V3_P: C170.2, C171.2, R91.2, R111.2, R112.2, SW3.2, TP10.1, U6.3 (VOUT); also elsewhere on the board
+12V: C2.2, C174.2, C175.2, C176.2, C180.2, C228.2, J18.1, R113.2, R142.2, R143.2, R144.2, R145.2, R146.2, U3.7 (VIN-), U4.1 (VIN), U5.1 (VIN), U6.1 (VIN), U10.1 (VIN), U11.1 (VIN); also elsewhere on the board
DDRVCC: C181.2, C223.2, R100.2, R101.2, R150.2, TP8.1, U11.3 (VOUT), U20.1 (VIN); also elsewhere on the board
DDRVREF: C226.2, R150.1, R151.2, U20.3 (~VREFEN~{}); also elsewhere on the board
DDRVTT: C224.2, U20.4 (VOUT); also elsewhere on the board
FPGA_DONE: J18.4; also elsewhere on the board
GND: C1.1, C2.1, C53.1, C170.1, C171.1, C172.1, C173.1, C174.1, C175.1, C176.1, C177.1, C178.1, C179.1, C180.1, C181.1, C218.1, C219.1, C223.1, C224.1, C225.1, C226.1, C228.1, D6.2 (A), J10.2, J18.7, J18.8, LD2.1 (C), R2.1, R92.2, R93.2, R96.1, R97.1, R98.1, R149.1, R151.1, R152.1, R169.1, R177.1, R178.1, R179.1, R180.1, R181.1, U3.1 (A1), U3.2 (A0), U3.6 (GND), U4.4 (PGND), U5.4 (PGND), U6.4 (PGND), U10.4 (PGND), U11.4 (PGND), U20.2 (GND), U20.9 (EXP), U23.4 (GND), U23.9 (EP), U24.3 (GND), U25.3 (GND); also elsewhere on the board
I2C_SCL: J18.6, U3.4 (SCL); also elsewhere on the board
I2C_SDA: J18.5, U3.3 (SDA); also elsewhere on the board
unnamed: D2.2 (A), Q4.4 (G), R152.2
unnamed: D3.2 (A), R154.2, TP14.1, U24.2 (IN), U25.2 (IN)
unnamed: D3.1 (K), TP6.1, U6.5 (PG), U11.5 (PG), U23.6 (PG)
unnamed: D5.1 (K), J18.2
unnamed: D6.1 (K), LD1.1 (C)
unnamed: LD1.2 (A), R111.1, R112.1
unnamed: LD2.2 (A), R148.1, U25.4 (OUT)
unnamed: J10.1, Q4.5 (D)
unnamed: R196.2, SW3.1
unnamed: R142.1, R177.2, U4.6 (EN)
unnamed: R1.1, R2.2, U4.7 (FB)
unnamed: R143.1, R178.2, U4.5 (PG), U5.6 (EN)
unnamed: R95.1, R96.2, R97.2, U5.7 (FB)
unnamed: C179.2, R91.1, R92.1, R196.1, U6.7 (FB)
unnamed: R144.1, R145.1, R179.2, R180.2, U5.5 (PG), U10.6 (EN), U11.6 (EN)
unnamed: C178.2, R93.1, R94.2, U10.7 (FB)
unnamed: R146.1, R181.2, U6.6 (EN), U10.5 (PG)
unnamed: R98.2, R100.1, R101.1, R169.2, U11.7 (FB)
RST: D5.2 (A), TP5.1, U24.4 (OUT); also elsewhere on the board
VCC_IN: D2.1 (C), D4.1 (K), Q4.1 (S), Q4.2 (S), Q4.3 (S), R113.1, U3.8 (VIN+)
VCC_USB: D4.2 (A); also elsewhere on the board

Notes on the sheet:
DDR VCC R169 R98 1.5V DNP Yes -> 1.35V Yes DNP
POWER OK
PMOD VCC SW3 3.3V ON -> 5.0V OFF

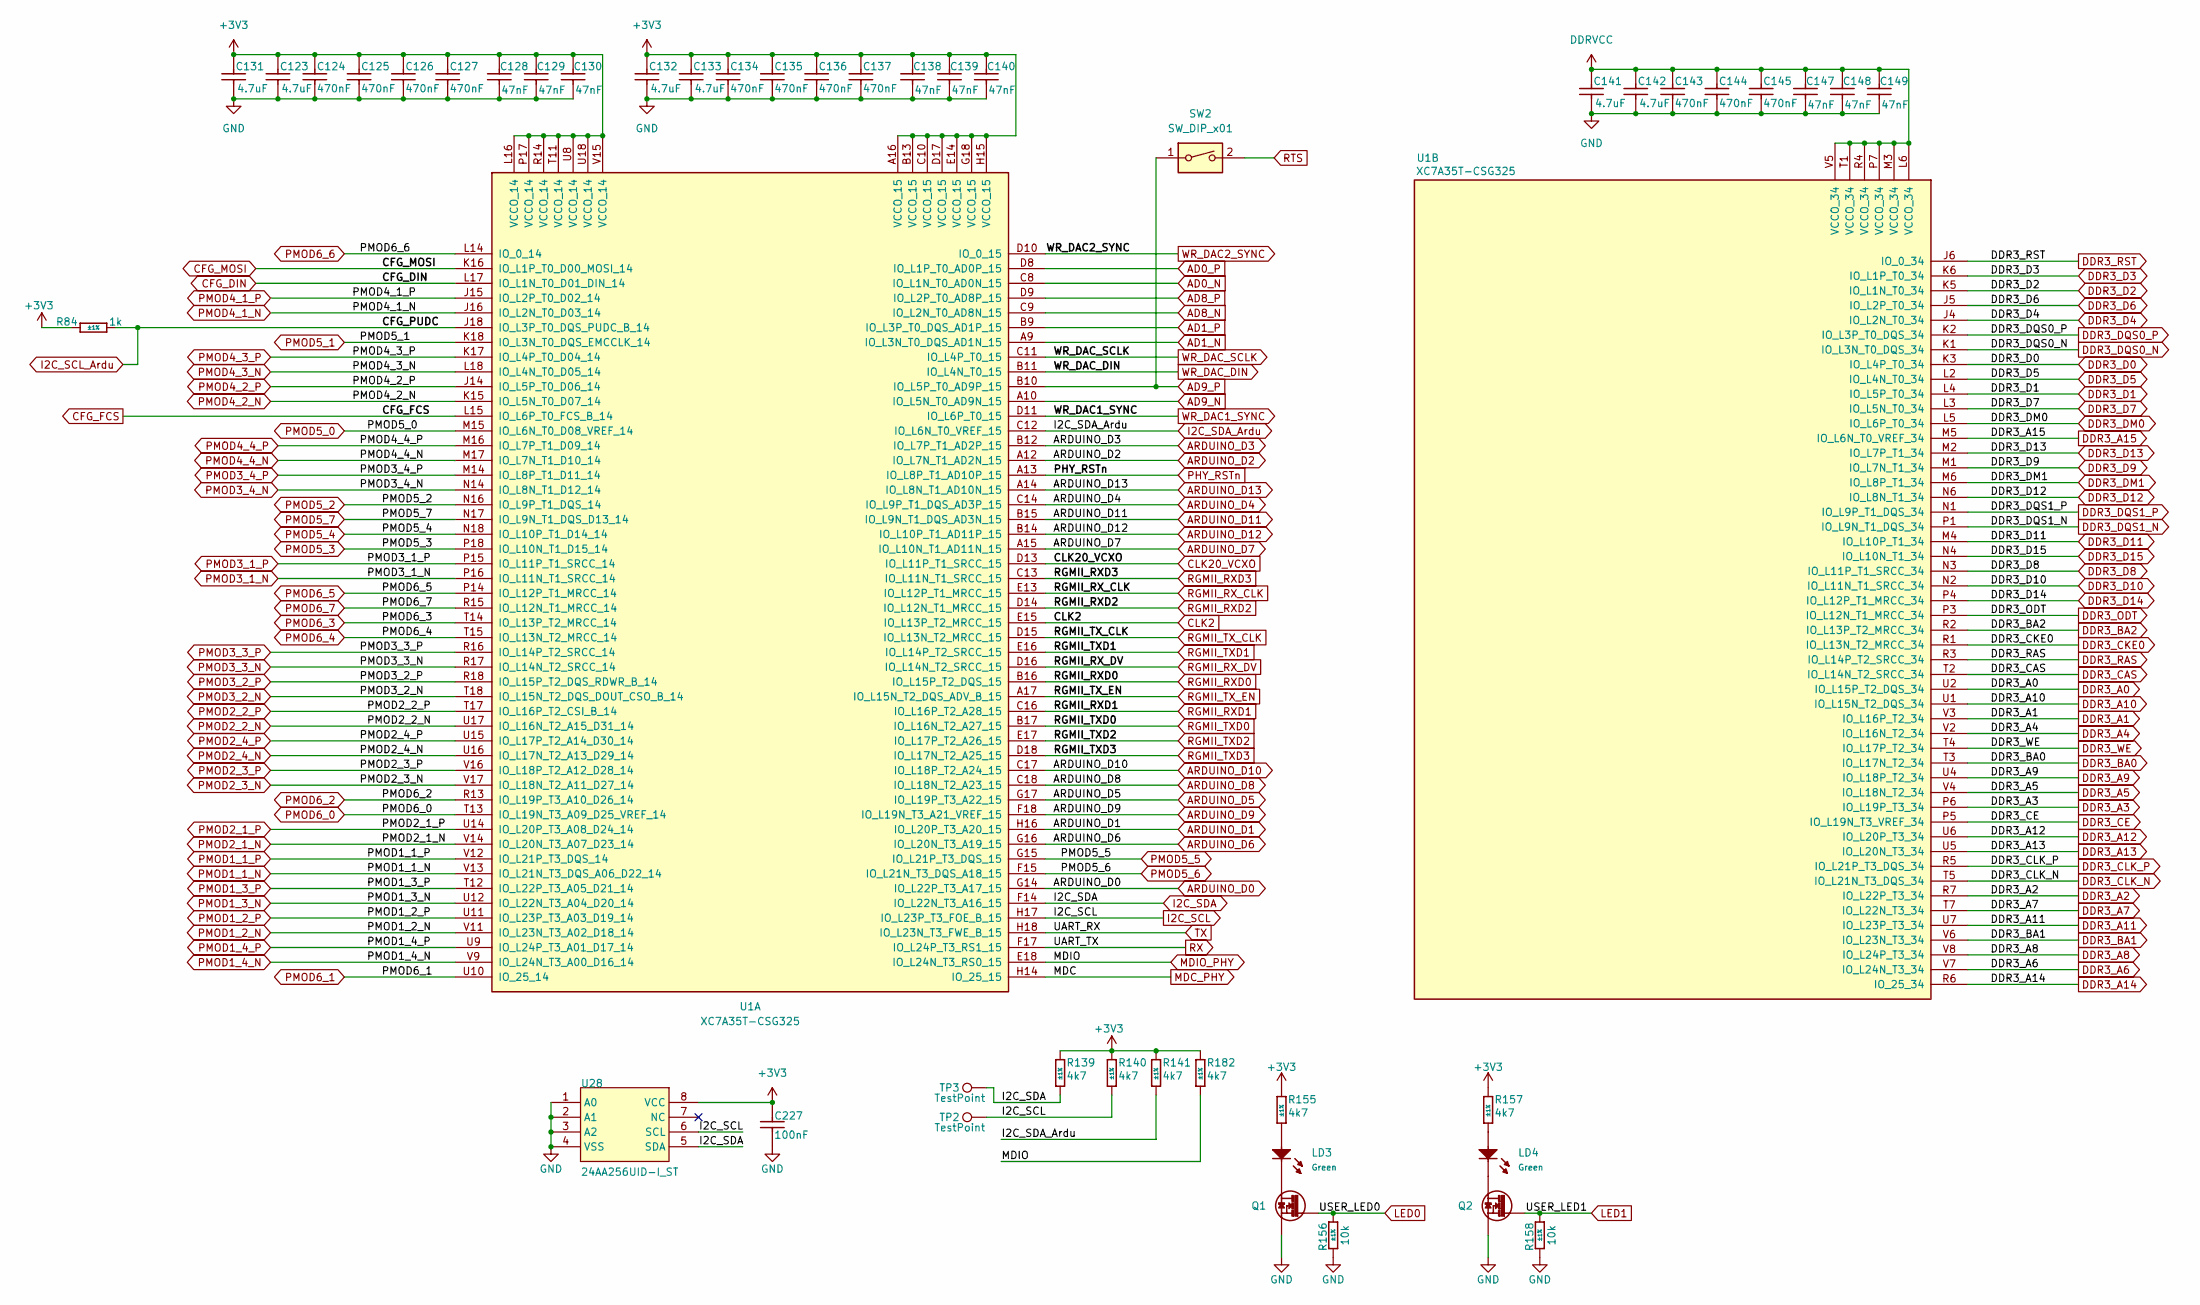
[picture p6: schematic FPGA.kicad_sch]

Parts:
C123, C131, C132, C133, C141, C142: CC0402_4.7UF_16V_20%_X5R; CAPC1005X55N; Voltage 16V; Tolerance ±20%; Part Number CC0402_4.7UF_16V_20%_X5R
C124, C125, C126, C127, C134, C135, C136, C137, C143, C144, C145: CC0201_470NF_4V_20%_X5R; CAPC0603X33N; Voltage 4V; Tolerance ±20%; Part Number CC0201_470NF_4V_20%_X5R
C128, C129, C130, C138, C139, C140, C147, C148, C149: CC0201_47NF_6.3V_10%_X5R; CAPC0603X33N; Voltage 6.3V; Tolerance ±10%; Part Number CC0201_47NF_6.3V_10%_X5R
C227: CC0402_100NF_50V_10%_X7R; CAPC1005X55N; Voltage 50V; Tolerance ±10%; Part Number CC0402_100NF_50V_10%_X7R
LD3, LD4: LED_KINGBRIGHT_KPH-1608CGCK; Part Number LED_KINGBRIGHT_KPH-1608CGCK
Q1, Q2: BSS138LT1G; SOT95P240X110-3N; Part Number BSS138LT1G
R84: R0402_1K_1%_0.0625W_100PPM; RESC1005X40N; Tolerance ±1%; Part Number R0402_1K_1%_0.0625W_100PPM
R139, R140, R141, R155, R157, R182: R0402_4K7_1%_0.0625W_100PPM; RESC1005X40N; Tolerance ±1%; Part Number R0402_4K7_1%_0.0625W_100PPM
R156, R158: R0402_10K_1%_0.0625W_100PPM; RESC1005X40N; Tolerance ±1%; Part Number R0402_10K_1%_0.0625W_100PPM
SW2: SW_DIP_x01; SW_OMRON_A6SN-1101
TP2, TP3: TestPoint; TestPoint_Pad_D1.5mm
U1: XC7A35T-CSG325; Xilinx_CSG325
U28: 24AA256UID-I_ST; SOP65P640X120-8N; MANUFACTURER_PART_NUMBER 24AA256UID-I/ST; MOUSER PART NUMBER 579-24AA256UID-I/ST

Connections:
+3V3: C123.2, C124.2, C125.2, C126.2, C127.2, C128.2, C129.2, C130.2, C131.2, C132.2, C133.2, C134.2, C135.2, C136.2, C137.2, C138.2, C139.2, C140.2, C227.2, R84.1, R139.2, R140.2, R141.2, R155.2, R157.2, R182.2, U1.A16 (VCCO_15), U1.B13 (VCCO_15), U1.C10 (VCCO_15), U1.D17 (VCCO_15), U1.E14 (VCCO_15), U1.G18 (VCCO_15), U1.H15 (VCCO_15), U1.L16 (VCCO_14), U1.P17 (VCCO_14), U1.R14 (VCCO_14), U1.T11 (VCCO_14), U1.U8 (VCCO_14), U1.U18 (VCCO_14), U1.V15 (VCCO_14), U28.8 (VCC); also elsewhere on the board
AD0_N: U1.C8 (IO_L1N_T0_AD0N_15); also elsewhere on the board
AD0_P: U1.D8 (IO_L1P_T0_AD0P_15); also elsewhere on the board
AD1_N: U1.A9 (IO_L3N_T0_DQS_AD1N_15); also elsewhere on the board
AD1_P: U1.B9 (IO_L3P_T0_DQS_AD1P_15); also elsewhere on the board
AD8_N: U1.C9 (IO_L2N_T0_AD8N_15); also elsewhere on the board
AD8_P: U1.D9 (IO_L2P_T0_AD8P_15); also elsewhere on the board
AD9_N: U1.A10 (IO_L5N_T0_AD9N_15); also elsewhere on the board
AD9_P: SW2.1, U1.B10 (IO_L5P_T0_AD9P_15); also elsewhere on the board
ARDUINO_D0: U1.G14 (IO_L22P_T3_A17_15); also elsewhere on the board
ARDUINO_D1: U1.H16 (IO_L20P_T3_A20_15); also elsewhere on the board
ARDUINO_D2: U1.A12 (IO_L7N_T1_AD2N_15); also elsewhere on the board
ARDUINO_D3: U1.B12 (IO_L7P_T1_AD2P_15); also elsewhere on the board
ARDUINO_D4: U1.C14 (IO_L9P_T1_DQS_AD3P_15); also elsewhere on the board
ARDUINO_D5: U1.G17 (IO_L19P_T3_A22_15); also elsewhere on the board
ARDUINO_D6: U1.G16 (IO_L20N_T3_A19_15); also elsewhere on the board
ARDUINO_D7: U1.A15 (IO_L10N_T1_AD11N_15); also elsewhere on the board
ARDUINO_D8: U1.C18 (IO_L18N_T2_A23_15); also elsewhere on the board
ARDUINO_D9: U1.F18 (IO_L19N_T3_A21_VREF_15); also elsewhere on the board
ARDUINO_D10: U1.C17 (IO_L18P_T2_A24_15); also elsewhere on the board
ARDUINO_D11: U1.B15 (IO_L9N_T1_DQS_AD3N_15); also elsewhere on the board
ARDUINO_D12: U1.B14 (IO_L10P_T1_AD11P_15); also elsewhere on the board
ARDUINO_D13: U1.A14 (IO_L8N_T1_AD10N_15); also elsewhere on the board
CFG_DIN: U1.L17 (IO_L1N_T0_D01_DIN_14); also elsewhere on the board
CFG_FCS: U1.L15 (IO_L6P_T0_FCS_B_14); also elsewhere on the board
CFG_MOSI: U1.K16 (IO_L1P_T0_D00_MOSI_14); also elsewhere on the board
CLK2: U1.E15 (IO_L13P_T2_MRCC_15); also elsewhere on the board
CLK20_VCXO: U1.D13 (IO_L11P_T1_SRCC_15); also elsewhere on the board
DDR3_A0: U1.U2 (IO_L15P_T2_DQS_34); also elsewhere on the board
DDR3_A1: U1.V3 (IO_L16P_T2_34); also elsewhere on the board
DDR3_A2: U1.R7 (IO_L22P_T3_34); also elsewhere on the board
DDR3_A3: U1.P6 (IO_L19P_T3_34); also elsewhere on the board
DDR3_A4: U1.V2 (IO_L16N_T2_34); also elsewhere on the board
DDR3_A5: U1.V4 (IO_L18N_T2_34); also elsewhere on the board
DDR3_A6: U1.V7 (IO_L24N_T3_34); also elsewhere on the board
DDR3_A7: U1.T7 (IO_L22N_T3_34); also elsewhere on the board
DDR3_A8: U1.V8 (IO_L24P_T3_34); also elsewhere on the board
DDR3_A9: U1.U4 (IO_L18P_T2_34); also elsewhere on the board
DDR3_A10: U1.U1 (IO_L15N_T2_DQS_34); also elsewhere on the board
DDR3_A11: U1.U7 (IO_L23P_T3_34); also elsewhere on the board
DDR3_A12: U1.U6 (IO_L20P_T3_34); also elsewhere on the board
DDR3_A13: U1.U5 (IO_L20N_T3_34); also elsewhere on the board
DDR3_A14: U1.R6 (IO_25_34); also elsewhere on the board
DDR3_A15: U1.M5 (IO_L6N_T0_VREF_34); also elsewhere on the board
DDR3_BA0: U1.T3 (IO_L17N_T2_34); also elsewhere on the board
DDR3_BA1: U1.V6 (IO_L23N_T3_34); also elsewhere on the board
DDR3_BA2: U1.R2 (IO_L13P_T2_MRCC_34); also elsewhere on the board
DDR3_CAS: U1.T2 (IO_L14N_T2_SRCC_34); also elsewhere on the board
DDR3_CE: U1.P5 (IO_L19N_T3_VREF_34); also elsewhere on the board
DDR3_CKE0: U1.R1 (IO_L13N_T2_MRCC_34); also elsewhere on the board
DDR3_CLK_N: U1.T5 (IO_L21N_T3_DQS_34); also elsewhere on the board
DDR3_CLK_P: U1.R5 (IO_L21P_T3_DQS_34); also elsewhere on the board
DDR3_D0: U1.K3 (IO_L4P_T0_34); also elsewhere on the board
DDR3_D1: U1.L4 (IO_L5P_T0_34); also elsewhere on the board
DDR3_D2: U1.K5 (IO_L1N_T0_34); also elsewhere on the board
DDR3_D3: U1.K6 (IO_L1P_T0_34); also elsewhere on the board
DDR3_D4: U1.J4 (IO_L2N_T0_34); also elsewhere on the board
DDR3_D5: U1.L2 (IO_L4N_T0_34); also elsewhere on the board
DDR3_D6: U1.J5 (IO_L2P_T0_34); also elsewhere on the board
DDR3_D7: U1.L3 (IO_L5N_T0_34); also elsewhere on the board
DDR3_D8: U1.N3 (IO_L11P_T1_SRCC_34); also elsewhere on the board
DDR3_D9: U1.M1 (IO_L7N_T1_34); also elsewhere on the board
DDR3_D10: U1.N2 (IO_L11N_T1_SRCC_34); also elsewhere on the board
DDR3_D11: U1.M4 (IO_L10P_T1_34); also elsewhere on the board
DDR3_D12: U1.N6 (IO_L8N_T1_34); also elsewhere on the board
DDR3_D13: U1.M2 (IO_L7P_T1_34); also elsewhere on the board
DDR3_D14: U1.P4 (IO_L12P_T1_MRCC_34); also elsewhere on the board
DDR3_D15: U1.N4 (IO_L10N_T1_34); also elsewhere on the board
DDR3_DM0: U1.L5 (IO_L6P_T0_34); also elsewhere on the board
DDR3_DM1: U1.M6 (IO_L8P_T1_34); also elsewhere on the board
DDR3_DQS0_N: U1.K1 (IO_L3N_T0_DQS_34); also elsewhere on the board
DDR3_DQS0_P: U1.K2 (IO_L3P_T0_DQS_34); also elsewhere on the board
DDR3_DQS1_N: U1.P1 (IO_L9N_T1_DQS_34); also elsewhere on the board
DDR3_DQS1_P: U1.N1 (IO_L9P_T1_DQS_34); also elsewhere on the board
DDR3_ODT: U1.P3 (IO_L12N_T1_MRCC_34); also elsewhere on the board
DDR3_RAS: U1.R3 (IO_L14P_T2_SRCC_34); also elsewhere on the board
DDR3_RST: U1.J6 (IO_0_34); also elsewhere on the board
DDR3_WE: U1.T4 (IO_L17P_T2_34); also elsewhere on the board
DDRVCC: C141.2, C142.2, C143.2, C144.2, C145.2, C147.2, C148.2, C149.2, U1.L6 (VCCO_34), U1.M3 (VCCO_34), U1.P7 (VCCO_34), U1.R4 (VCCO_34), U1.T1 (VCCO_34), U1.V5 (VCCO_34); also elsewhere on the board
GND: C123.1, C124.1, C125.1, C126.1, C127.1, C128.1, C129.1, C130.1, C131.1, C132.1, C133.1, C134.1, C135.1, C136.1, C137.1, C138.1, C139.1, C140.1, C141.1, C142.1, C143.1, C144.1, C145.1, C147.1, C148.1, C149.1, C227.1, Q1.2 (S), Q2.2 (S), R156.1, R158.1, U28.1 (A0), U28.2 (A1), U28.3 (A2), U28.4 (VSS); also elsewhere on the board
I2C_SCL: R140.1, TP2.1, U1.H17 (IO_L23P_T3_FOE_B_15), U28.6 (SCL); also elsewhere on the board
I2C_SCL_Ardu: R84.2, U1.J18 (IO_L3P_T0_DQS_PUDC_B_14); also elsewhere on the board
I2C_SDA: R139.1, TP3.1, U1.F14 (IO_L22N_T3_A16_15), U28.5 (SDA); also elsewhere on the board
I2C_SDA_Ardu: R141.1, U1.C12 (IO_L6N_T0_VREF_15); also elsewhere on the board
LED0: Q1.1 (G), R156.2; also elsewhere on the board
LED1: Q2.1 (G), R158.2; also elsewhere on the board
MDC_PHY: U1.H14 (IO_25_15); also elsewhere on the board
MDIO_PHY: R182.1, U1.E18 (IO_L24N_T3_RS0_15); also elsewhere on the board
unnamed: LD3.2 (A), R155.1
unnamed: LD3.1 (C), Q1.3 (D)
unnamed: LD4.2 (A), R157.1
unnamed: LD4.1 (C), Q2.3 (D)
PHY_RSTn: U1.A13 (IO_L8P_T1_AD10P_15); also elsewhere on the board
PMOD1_1_N: U1.V13 (IO_L21N_T3_DQS_A06_D22_14); also elsewhere on the board
PMOD1_1_P: U1.V12 (IO_L21P_T3_DQS_14); also elsewhere on the board
PMOD1_2_N: U1.V11 (IO_L23N_T3_A02_D18_14); also elsewhere on the board
PMOD1_2_P: U1.U11 (IO_L23P_T3_A03_D19_14); also elsewhere on the board
PMOD1_3_N: U1.U12 (IO_L22N_T3_A04_D20_14); also elsewhere on the board
PMOD1_3_P: U1.T12 (IO_L22P_T3_A05_D21_14); also elsewhere on the board
PMOD1_4_N: U1.V9 (IO_L24N_T3_A00_D16_14); also elsewhere on the board
PMOD1_4_P: U1.U9 (IO_L24P_T3_A01_D17_14); also elsewhere on the board
PMOD2_1_N: U1.V14 (IO_L20N_T3_A07_D23_14); also elsewhere on the board
PMOD2_1_P: U1.U14 (IO_L20P_T3_A08_D24_14); also elsewhere on the board
PMOD2_2_N: U1.U17 (IO_L16N_T2_A15_D31_14); also elsewhere on the board
PMOD2_2_P: U1.T17 (IO_L16P_T2_CSI_B_14); also elsewhere on the board
PMOD2_3_N: U1.V17 (IO_L18N_T2_A11_D27_14); also elsewhere on the board
PMOD2_3_P: U1.V16 (IO_L18P_T2_A12_D28_14); also elsewhere on the board
PMOD2_4_N: U1.U16 (IO_L17N_T2_A13_D29_14); also elsewhere on the board
PMOD2_4_P: U1.U15 (IO_L17P_T2_A14_D30_14); also elsewhere on the board
PMOD3_1_N: U1.P16 (IO_L11N_T1_SRCC_14); also elsewhere on the board
PMOD3_1_P: U1.P15 (IO_L11P_T1_SRCC_14); also elsewhere on the board
PMOD3_2_N: U1.T18 (IO_L15N_T2_DQS_DOUT_CSO_B_14); also elsewhere on the board
PMOD3_2_P: U1.R18 (IO_L15P_T2_DQS_RDWR_B_14); also elsewhere on the board
PMOD3_3_N: U1.R17 (IO_L14N_T2_SRCC_14); also elsewhere on the board
PMOD3_3_P: U1.R16 (IO_L14P_T2_SRCC_14); also elsewhere on the board
PMOD3_4_N: U1.N14 (IO_L8N_T1_D12_14); also elsewhere on the board
PMOD3_4_P: U1.M14 (IO_L8P_T1_D11_14); also elsewhere on the board
PMOD4_1_N: U1.J16 (IO_L2N_T0_D03_14); also elsewhere on the board
PMOD4_1_P: U1.J15 (IO_L2P_T0_D02_14); also elsewhere on the board
PMOD4_2_N: U1.K15 (IO_L5N_T0_D07_14); also elsewhere on the board
PMOD4_2_P: U1.J14 (IO_L5P_T0_D06_14); also elsewhere on the board
PMOD4_3_N: U1.L18 (IO_L4N_T0_D05_14); also elsewhere on the board
PMOD4_3_P: U1.K17 (IO_L4P_T0_D04_14); also elsewhere on the board
PMOD4_4_N: U1.M17 (IO_L7N_T1_D10_14); also elsewhere on the board
PMOD4_4_P: U1.M16 (IO_L7P_T1_D09_14); also elsewhere on the board
PMOD5_0: U1.M15 (IO_L6N_T0_D08_VREF_14); also elsewhere on the board
PMOD5_1: U1.K18 (IO_L3N_T0_DQS_EMCCLK_14); also elsewhere on the board
PMOD5_2: U1.N16 (IO_L9P_T1_DQS_14); also elsewhere on the board
PMOD5_3: U1.P18 (IO_L10N_T1_D15_14); also elsewhere on the board
PMOD5_4: U1.N18 (IO_L10P_T1_D14_14); also elsewhere on the board
PMOD5_5: U1.G15 (IO_L21P_T3_DQS_15); also elsewhere on the board
PMOD5_6: U1.F15 (IO_L21N_T3_DQS_A18_15); also elsewhere on the board
PMOD5_7: U1.N17 (IO_L9N_T1_DQS_D13_14); also elsewhere on the board
PMOD6_0: U1.T13 (IO_L19N_T3_A09_D25_VREF_14); also elsewhere on the board
PMOD6_1: U1.U10 (IO_25_14); also elsewhere on the board
PMOD6_2: U1.R13 (IO_L19P_T3_A10_D26_14); also elsewhere on the board
PMOD6_3: U1.T14 (IO_L13P_T2_MRCC_14); also elsewhere on the board
PMOD6_4: U1.T15 (IO_L13N_T2_MRCC_14); also elsewhere on the board
PMOD6_5: U1.P14 (IO_L12P_T1_MRCC_14); also elsewhere on the board
PMOD6_6: U1.L14 (IO_0_14); also elsewhere on the board
PMOD6_7: U1.R15 (IO_L12N_T1_MRCC_14); also elsewhere on the board
RGMII_RXD0: U1.B16 (IO_L15P_T2_DQS_15); also elsewhere on the board
RGMII_RXD1: U1.C16 (IO_L16P_T2_A28_15); also elsewhere on the board
RGMII_RXD2: U1.D14 (IO_L12N_T1_MRCC_15); also elsewhere on the board
RGMII_RXD3: U1.C13 (IO_L11N_T1_SRCC_15); also elsewhere on the board
RGMII_RX_CLK: U1.E13 (IO_L12P_T1_MRCC_15); also elsewhere on the board
RGMII_RX_DV: U1.D16 (IO_L14N_T2_SRCC_15); also elsewhere on the board
RGMII_TXD0: U1.B17 (IO_L16N_T2_A27_15); also elsewhere on the board
RGMII_TXD1: U1.E16 (IO_L14P_T2_SRCC_15); also elsewhere on the board
RGMII_TXD2: U1.E17 (IO_L17P_T2_A26_15); also elsewhere on the board
RGMII_TXD3: U1.D18 (IO_L17N_T2_A25_15); also elsewhere on the board
RGMII_TX_CLK: U1.D15 (IO_L13N_T2_MRCC_15); also elsewhere on the board
RGMII_TX_EN: U1.A17 (IO_L15N_T2_DQS_ADV_B_15); also elsewhere on the board
RTS: SW2.2; also elsewhere on the board
RX: U1.F17 (IO_L24P_T3_RS1_15); also elsewhere on the board
TX: U1.H18 (IO_L23N_T3_FWE_B_15); also elsewhere on the board
WR_DAC1_SYNC: U1.D11 (IO_L6P_T0_15); also elsewhere on the board
WR_DAC2_SYNC: U1.D10 (IO_0_15); also elsewhere on the board
WR_DAC_DIN: U1.B11 (IO_L4N_T0_15); also elsewhere on the board
WR_DAC_SCLK: U1.C11 (IO_L4P_T0_15); also elsewhere on the board

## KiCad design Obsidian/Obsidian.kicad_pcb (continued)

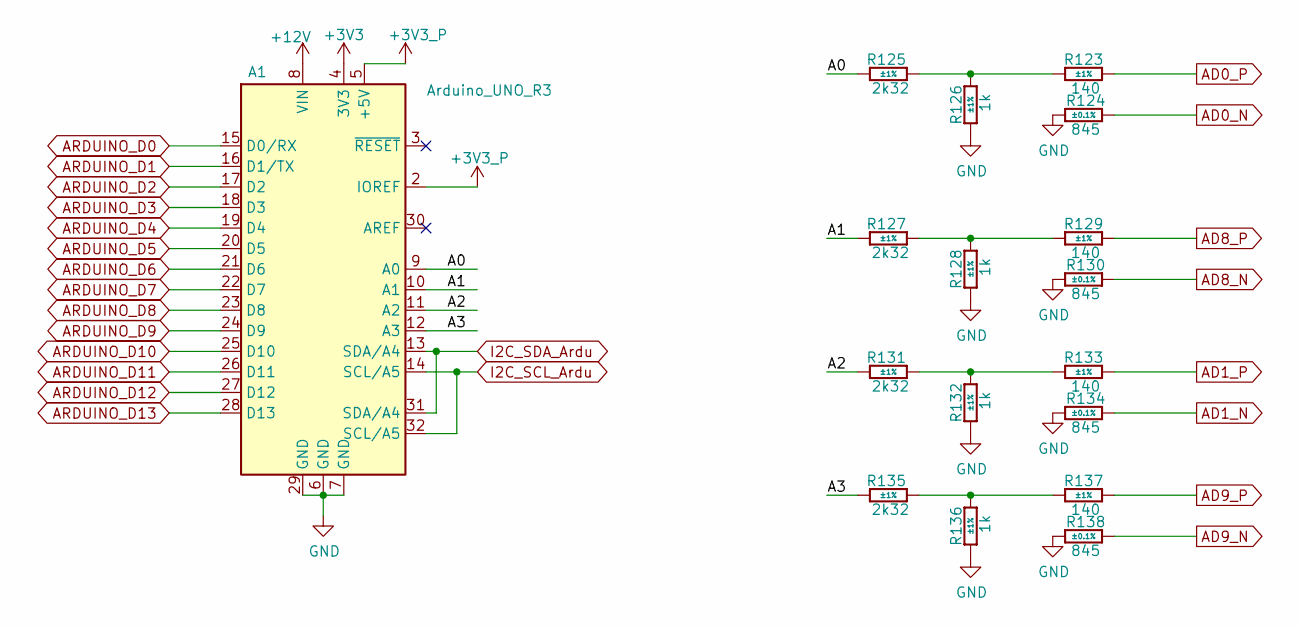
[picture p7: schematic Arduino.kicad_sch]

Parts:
A1: Arduino_UNO_R3
R123, R129, R133, R137: R0402_140R_1%_0.0625W_100PPM; RESC1005X40N; Tolerance ±1%; Part Number R0402_140R_1%_0.0625W_100PPM
R124, R130, R134, R138: R0402_845R_0.1%_0.063W_25PPM; RESC1005X40N; Tolerance ±0.1%; Part Number R0402_845R_0.1%_0.063W_25PPM
R125, R127, R131, R135: R0402_2K32_1%_0.0625W_100PPM; RESC1005X40N; Tolerance ±1%; Part Number R0402_2K32_1%_0.0625W_100PPM
R126, R128, R132, R136: R0402_1K_1%_0.0625W_100PPM; RESC1005X40N; Tolerance ±1%; Part Number R0402_1K_1%_0.0625W_100PPM

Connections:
+3V3: A1.4 (3V3); also elsewhere on the board
+3V3_P: A1.2 (IOREF), A1.5 (+5V); also elsewhere on the board
+12V: A1.8 (VIN); also elsewhere on the board
/Arduino/A0: A1.9 (A0), R125.1
/Arduino/A1: A1.10 (A1), R127.1
/Arduino/A2: A1.11 (A2), R131.1
/Arduino/A3: A1.12 (A3), R135.1
AD0_N: R124.2; also elsewhere on the board
AD0_P: R123.2; also elsewhere on the board
AD1_N: R134.2; also elsewhere on the board
AD1_P: R133.2; also elsewhere on the board
AD8_N: R130.2; also elsewhere on the board
AD8_P: R129.2; also elsewhere on the board
AD9_N: R138.2; also elsewhere on the board
AD9_P: R137.2; also elsewhere on the board
ARDUINO_D0: A1.15 (D0/RX); also elsewhere on the board
ARDUINO_D1: A1.16 (D1/TX); also elsewhere on the board
ARDUINO_D2: A1.17 (D2); also elsewhere on the board
ARDUINO_D3: A1.18 (D3); also elsewhere on the board
ARDUINO_D4: A1.19 (D4); also elsewhere on the board
ARDUINO_D5: A1.20 (D5); also elsewhere on the board
ARDUINO_D6: A1.21 (D6); also elsewhere on the board
ARDUINO_D7: A1.22 (D7); also elsewhere on the board
ARDUINO_D8: A1.23 (D8); also elsewhere on the board
ARDUINO_D9: A1.24 (D9); also elsewhere on the board
ARDUINO_D10: A1.25 (D10); also elsewhere on the board
ARDUINO_D11: A1.26 (D11); also elsewhere on the board
ARDUINO_D12: A1.27 (D12); also elsewhere on the board
ARDUINO_D13: A1.28 (D13); also elsewhere on the board
GND: A1.6 (GND), A1.7 (GND), A1.29 (GND), R124.1, R126.2, R128.2, R130.1, R132.2, R134.1, R136.2, R138.1; also elsewhere on the board
I2C_SCL_Ardu: A1.14 (SCL/A5), A1.32 (SCL/A5); also elsewhere on the board
I2C_SDA_Ardu: A1.13 (SDA/A4), A1.31 (SDA/A4); also elsewhere on the board
unnamed: R123.1, R125.2, R126.1
unnamed: R127.2, R128.1, R129.1
unnamed: R131.2, R132.1, R133.1
unnamed: R135.2, R136.1, R137.1

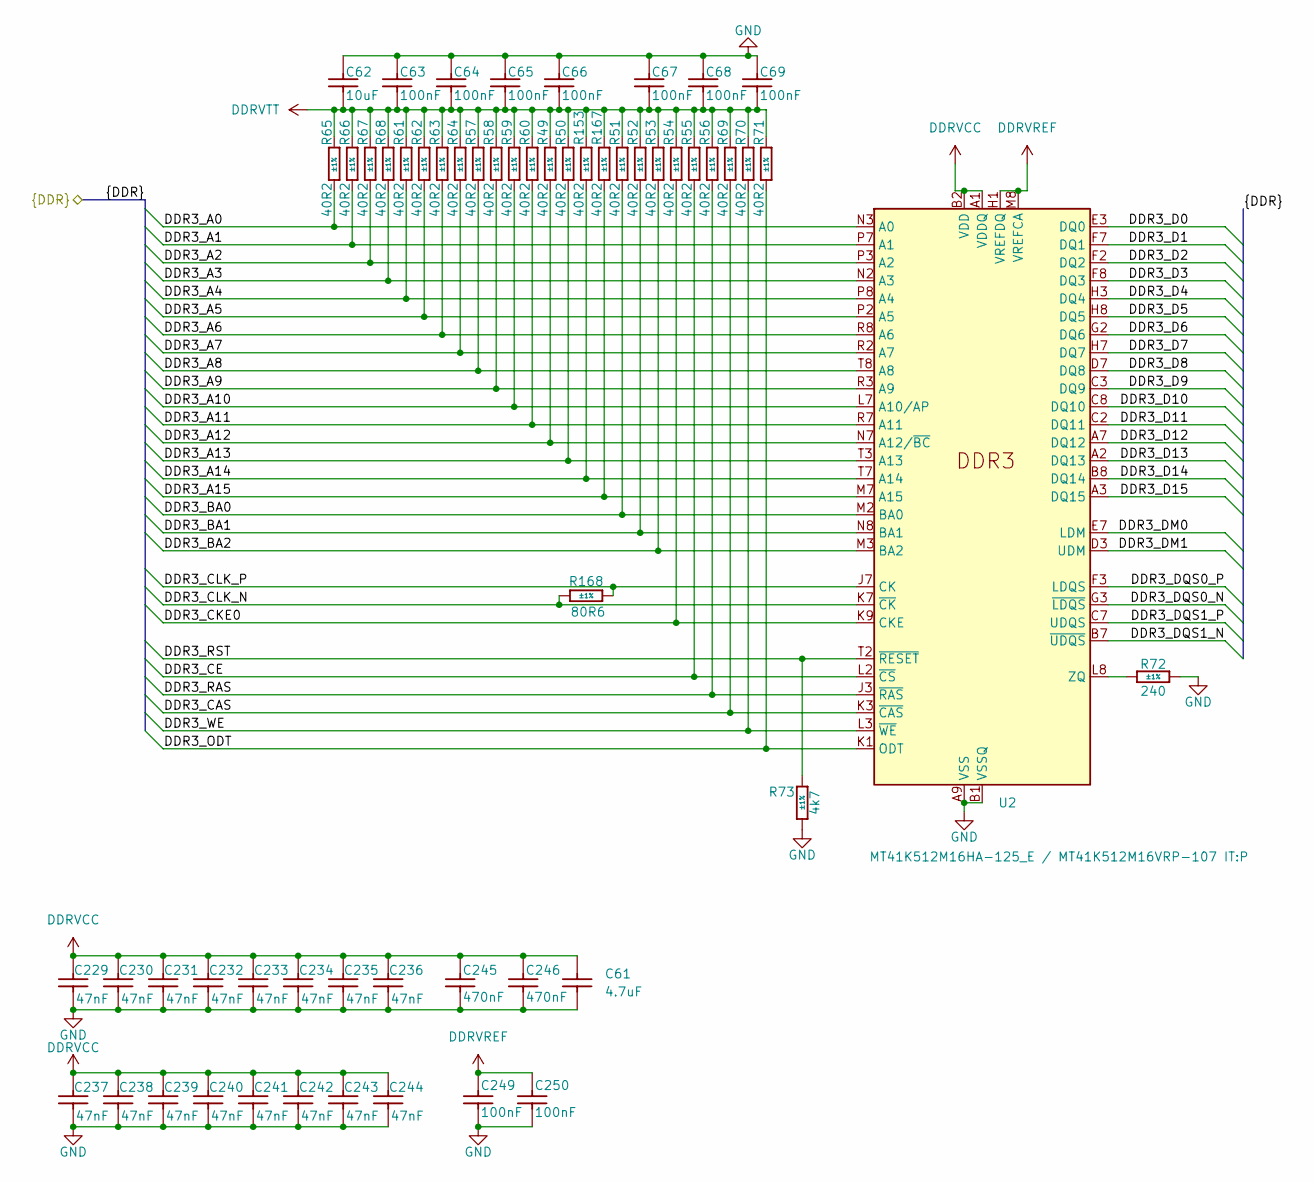
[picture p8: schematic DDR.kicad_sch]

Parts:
C61: CC0402_4.7UF_16V_20%_X5R; CAPC1005X55N; Voltage 16V; Tolerance ±20%; Part Number CC0402_4.7UF_16V_20%_X5R; LCSC C318563
C62: CC0402_10UF_6.3V_20%_X5R; CAPC1005X70N; Voltage 6.3V; Tolerance ±10%; Part Number CC0402_10UF_6.3V_20%_X5R; LCSC C76991
C63, C64, C65, C66, C67, C68, C69: CC0402_100NF_50V_10%_X7R; CAPC1005X55N; Voltage 50V; Tolerance ±10%; Part Number CC0402_100NF_50V_10%_X7R; LCSC C110251
C229, C230, C231, C232, C233, C234, C235, C236, C237, C238, C239, C240, C241, C242, C243, C244: CC0201_47NF_6.3V_10%_X5R; CAPC0603X33N; Voltage 6.3V; Tolerance ±10%; Part Number CC0201_47NF_6.3V_10%_X5R; LCSC C565524
C245, C246: CC0201_470NF_4V_20%_X5R; CAPC0603X33N; Voltage 4V; Tolerance ±20%; Part Number CC0201_470NF_4V_20%_X5R; LCSC C85926
C249, C250: CC0201_100NF_6.3V_10%_X5R; CAPC0603X33N; Voltage 6.3V; Tolerance ±10%; Part Number CC0201_100NF_6.3V_10%_X5R; LCSC C190187
R49, R50, R51, R52, R53, R54, R55, R56, R57, R58, R59, R60, R61, R62, R63, R64, R65, R66, R67, R68, R69, R70, R71, R153, R167: R0402_40R2_1%_0.0625W_100PPM; RESC1005X40N; Tolerance ±1%; Part Number R0402_40R2_1%_0.0625W_100PPM; LCSC C25111
R72: R0402_240R_1%_0.0625W_100PPM; RESC1005X40N; Tolerance ±1%; Part Number R0402_240R_1%_0.0625W_100PPM; LCSC C25094
R73: R0402_4K7_1%_0.0625W_100PPM; RESC1005X40N; Tolerance ±1%; Part Number R0402_4K7_1%_0.0625W_100PPM; LCSC C25900
R168: R0402_80R6_1%_0.1W_100PPM; RESC1005X40N; Tolerance ±1%; Voltage 50V; Part Number R0402_80R6_1%_0.1W_100PPM; LCSC C2077034
U2: MT41K512M16HA-125_E / MT41K512M16VRP-107 IT:P; FBGA-96_9x14mm_Layout9x16_P0.8mm; LCSC C2831669

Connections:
DDR3_A0: R65.1, U2.N3 (A0); also elsewhere on the board
DDR3_A1: R66.1, U2.P7 (A1); also elsewhere on the board
DDR3_A2: R67.1, U2.P3 (A2); also elsewhere on the board
DDR3_A3: R68.1, U2.N2 (A3); also elsewhere on the board
DDR3_A4: R61.1, U2.P8 (A4); also elsewhere on the board
DDR3_A5: R62.1, U2.P2 (A5); also elsewhere on the board
DDR3_A6: R63.1, U2.R8 (A6); also elsewhere on the board
DDR3_A7: R64.1, U2.R2 (A7); also elsewhere on the board
DDR3_A8: R57.1, U2.T8 (A8); also elsewhere on the board
DDR3_A9: R58.1, U2.R3 (A9); also elsewhere on the board
DDR3_A10: R59.1, U2.L7 (A10/AP); also elsewhere on the board
DDR3_A11: R60.1, U2.R7 (A11); also elsewhere on the board
DDR3_A12: R49.1, U2.N7 (A12/~BC); also elsewhere on the board
DDR3_A13: R50.1, U2.T3 (A13); also elsewhere on the board
DDR3_A14: R153.1, U2.T7 (A14); also elsewhere on the board
DDR3_A15: R167.1, U2.M7 (A15); also elsewhere on the board
DDR3_BA0: R51.1, U2.M2 (BA0); also elsewhere on the board
DDR3_BA1: R52.1, U2.N8 (BA1); also elsewhere on the board
DDR3_BA2: R53.1, U2.M3 (BA2); also elsewhere on the board
DDR3_CAS: R69.1, U2.K3 (~CAS); also elsewhere on the board
DDR3_CE: R55.1, U2.L2 (~CS); also elsewhere on the board
DDR3_CKE0: R54.1, U2.K9 (CKE); also elsewhere on the board
DDR3_CLK_N: R168.1, U2.K7 (~CK); also elsewhere on the board
DDR3_CLK_P: R168.2, U2.J7 (CK); also elsewhere on the board
DDR3_D0: U2.E3 (DQ0); also elsewhere on the board
DDR3_D1: U2.F7 (DQ1); also elsewhere on the board
DDR3_D2: U2.F2 (DQ2); also elsewhere on the board
DDR3_D3: U2.F8 (DQ3); also elsewhere on the board
DDR3_D4: U2.H3 (DQ4); also elsewhere on the board
DDR3_D5: U2.H8 (DQ5); also elsewhere on the board
DDR3_D6: U2.G2 (DQ6); also elsewhere on the board
DDR3_D7: U2.H7 (DQ7); also elsewhere on the board
DDR3_D8: U2.D7 (DQ8); also elsewhere on the board
DDR3_D9: U2.C3 (DQ9); also elsewhere on the board
DDR3_D10: U2.C8 (DQ10); also elsewhere on the board
DDR3_D11: U2.C2 (DQ11); also elsewhere on the board
DDR3_D12: U2.A7 (DQ12); also elsewhere on the board
DDR3_D13: U2.A2 (DQ13); also elsewhere on the board
DDR3_D14: U2.B8 (DQ14); also elsewhere on the board
DDR3_D15: U2.A3 (DQ15); also elsewhere on the board
DDR3_DM0: U2.E7 (LDM); also elsewhere on the board
DDR3_DM1: U2.D3 (UDM); also elsewhere on the board
DDR3_DQS0_N: U2.G3 (~LDQS); also elsewhere on the board
DDR3_DQS0_P: U2.F3 (LDQS); also elsewhere on the board
DDR3_DQS1_N: U2.B7 (~UDQS); also elsewhere on the board
DDR3_DQS1_P: U2.C7 (UDQS); also elsewhere on the board
DDR3_ODT: R71.1, U2.K1 (ODT); also elsewhere on the board
DDR3_RAS: R56.1, U2.J3 (~RAS); also elsewhere on the board
DDR3_RST: R73.2, U2.T2 (~RESET); also elsewhere on the board
DDR3_WE: R70.1, U2.L3 (~WE); also elsewhere on the board
DDRVCC: C61.2, C229.2, C230.2, C231.2, C232.2, C233.2, C234.2, C235.2, C236.2, C237.2, C238.2, C239.2, C240.2, C241.2, C242.2, C243.2, C244.2, C245.2, C246.2, U2.A1 (VDDQ), U2.A8 (VDDQ), U2.B2 (VDD), U2.C1 (VDDQ), U2.C9 (VDDQ), U2.D2 (VDDQ), U2.D9 (VDD), U2.E9 (VDDQ), U2.F1 (VDDQ), U2.G7 (VDD), U2.H2 (VDDQ), U2.H9 (VDDQ), U2.K2 (VDD), U2.K8 (VDD), U2.N1 (VDD), U2.N9 (VDD), U2.R1 (VDD), U2.R9 (VDD); also elsewhere on the board
DDRVREF: C249.2, C250.2, U2.H1 (VREFDQ), U2.M8 (VREFCA); also elsewhere on the board
DDRVTT: C62.1, C63.1, C64.1, C65.1, C66.1, C67.1, C68.1, C69.1, R49.2, R50.2, R51.2, R52.2, R53.2, R54.2, R55.2, R56.2, R57.2, R58.2, R59.2, R60.2, R61.2, R62.2, R63.2, R64.2, R65.2, R66.2, R67.2, R68.2, R69.2, R70.2, R71.2, R153.2, R167.2; also elsewhere on the board
GND: C61.1, C62.2, C63.2, C64.2, C65.2, C66.2, C67.2, C68.2, C69.2, C229.1, C230.1, C231.1, C232.1, C233.1, C234.1, C235.1, C236.1, C237.1, C238.1, C239.1, C240.1, C241.1, C242.1, C243.1, C244.1, C245.1, C246.1, C249.1, C250.1, R72.2, R73.1, U2.A9 (VSS), U2.B1 (VSSQ), U2.B3 (VSS), U2.B9 (VSSQ), U2.D1 (VSSQ), U2.D8 (VSSQ), U2.E1 (VSS), U2.E2 (VSSQ), U2.E8 (VSSQ), U2.F9 (VSSQ), U2.G1 (VSSQ), U2.G8 (VSS), U2.G9 (VSSQ), U2.J2 (VSS), U2.J8 (VSS), U2.M1 (VSS), U2.M9 (VSS), U2.P1 (VSS), U2.P9 (VSS), U2.T1 (VSS), U2.T9 (VSS); also elsewhere on the board
unnamed: R72.1, U2.L8 (ZQ)

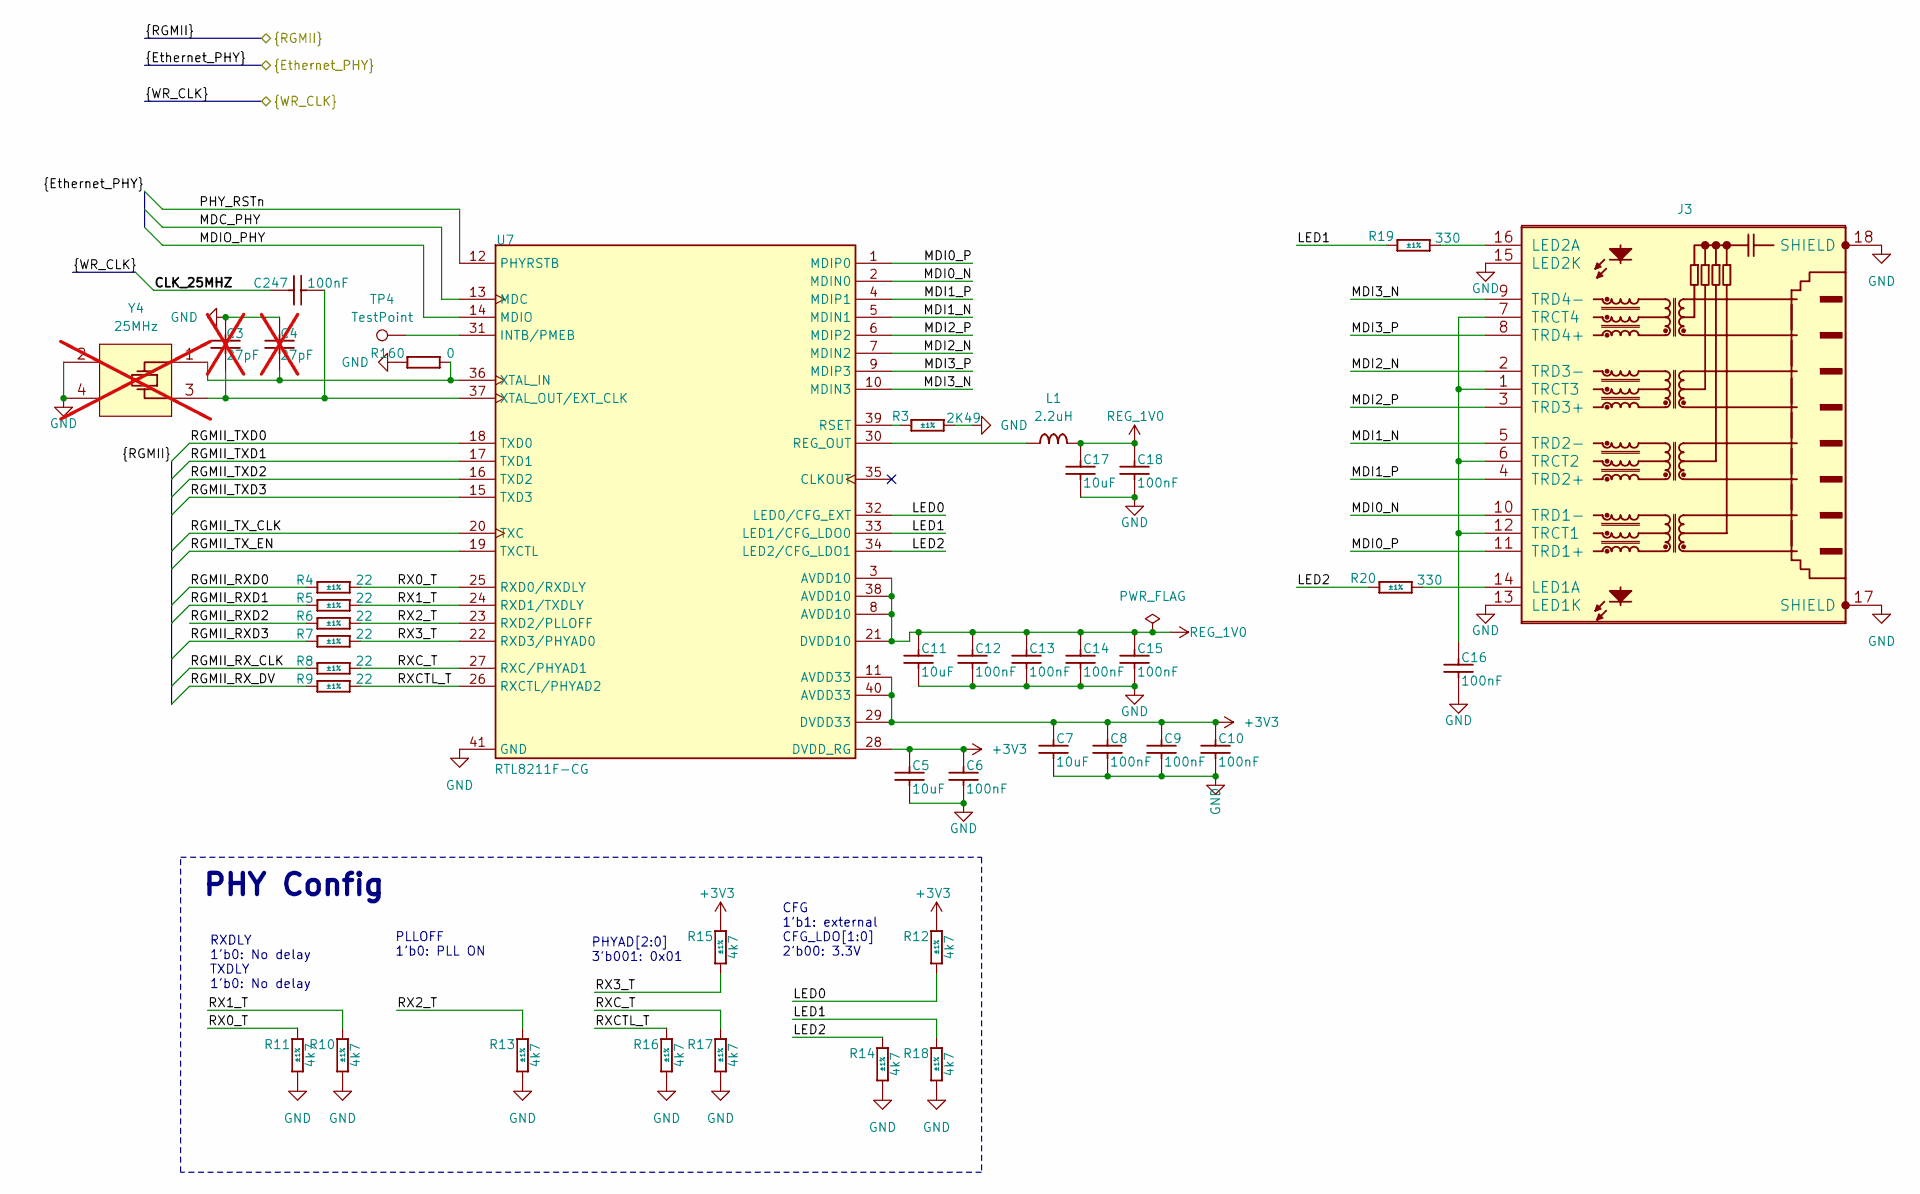
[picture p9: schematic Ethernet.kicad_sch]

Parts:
C3, C4: CC0402_27PF_50V_5%_C0G; CAPC1005X55N; Voltage 50V; Tolerance ±5%; Part Number CC0402_27PF_50V_5%_C0G; LCSC C126504; not fitted
C5, C7, C11, C17: CC0402_10UF_6.3V_20%_X5R; CAPC1005X70N; Voltage 6.3V; Tolerance ±10%; Part Number CC0402_10UF_6.3V_20%_X5R; LCSC C76991
C6, C8, C9, C10, C12, C13, C14, C15, C16, C18, C247: CC0402_100NF_50V_10%_X7R; CAPC1005X55N; Voltage 50V; Tolerance ±10%; Part Number CC0402_100NF_50V_10%_X7R; LCSC C110251
J3: BELFUSE_0826-1G1T-43-F; BEL_0826-1G1T-43-F; Part Number BELFUSE_0826-1G1T-43-F; LCSC C6776261
L1: IND_2.2UH_20%_BOURNS_SRP3212; IND_BOURNS_SRP3212; Tolerance ±20%; Part Number IND_2.2UH_20%_BOURNS_SRP3212; LCSC C6685204
R3: R0402_2K49_1%_0.063W_100PPM; RESC1005X40N; Tolerance ±1%; Part Number R0402_2K49_1%_0.063W_100PPM; LCSC C482132
R4, R5, R6, R7, R8, R9: R0402_22R_1%_0.0625W_100PPM; RESC1005X40N; Tolerance ±1%; Part Number R0402_22R_1%_0.0625W_100PPM; LCSC C25092
R10, R11, R12, R13, R14, R15, R16, R17, R18: R0402_4K7_1%_0.0625W_100PPM; RESC1005X40N; Tolerance ±1%; Part Number R0402_4K7_1%_0.0625W_100PPM; LCSC C25900
R19, R20: R0402_330R_1%_0.0625W_100PPM; RESC1005X40N; Tolerance ±1%; Part Number R0402_330R_1%_0.0625W_100PPM; LCSC C25104
R160: R0402_0R_JUMPER; RESC1005X40N; Part Number R0402_0R_JUMPER; LCSC C106231
TP4: TestPoint; TestPoint_Pad_D1.5mm
U7: RTL8211F-CG; QFN40P500X500X80-41N-S360; LCSC C187932
Y4: XTAL_25MHZ_EPSON_TSX-3225_25.0000MF10Z-AC; XTAL_EPSON_TSX-3225; Part Number XTAL_25MHZ_EPSON_TSX-3225_25.0000MF10Z-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; not fitted

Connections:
+3V3: C5.2, C6.2, C7.2, C8.2, C9.2, C10.2, R12.2, R15.2, U7.11 (AVDD33), U7.28 (DVDD_RG), U7.29 (DVDD33), U7.40 (AVDD33); also elsewhere on the board
/Ethernet/LED0: R12.1, U7.32 (LED0/CFG_EXT)
/Ethernet/LED1: R18.2, R19.1, U7.33 (LED1/CFG_LDO0)
/Ethernet/LED2: R14.2, R20.1, U7.34 (LED2/CFG_LDO1)
/Ethernet/MDI0_N: J3.10 (TRD1-), U7.2 (MDIN0)
/Ethernet/MDI0_P: J3.11 (TRD1+), U7.1 (MDIP0)
/Ethernet/MDI1_N: J3.5 (TRD2-), U7.5 (MDIN1)
/Ethernet/MDI1_P: J3.4 (TRD2+), U7.4 (MDIP1)
/Ethernet/MDI2_N: J3.2 (TRD3-), U7.7 (MDIN2)
/Ethernet/MDI2_P: J3.3 (TRD3+), U7.6 (MDIP2)
/Ethernet/MDI3_N: J3.9 (TRD4-), U7.10 (MDIN3)
/Ethernet/MDI3_P: J3.8 (TRD4+), U7.9 (MDIP3)
/Ethernet/RX0_T: R4.2, R11.2, U7.25 (RXD0/RXDLY)
/Ethernet/RX1_T: R5.2, R10.2, U7.24 (RXD1/TXDLY)
/Ethernet/RX2_T: R6.2, R13.2, U7.23 (RXD2/PLLOFF)
/Ethernet/RX3_T: R7.2, R15.1, U7.22 (RXD3/PHYAD0)
/Ethernet/RXCTL_T: R9.2, R16.2, U7.26 (RXCTL/PHYAD2)
/Ethernet/RXC_T: R8.2, R17.2, U7.27 (RXC/PHYAD1)
CLK_25MHZ: C247.2; also elsewhere on the board
GND: C3.2, C4.2, C5.1, C6.1, C7.1, C8.1, C9.1, C10.1, C11.1, C12.1, C13.1, C14.1, C15.1, C16.1, C17.1, C18.1, J3.13 (LED1K), J3.15 (LED2K), J3.17 (SHIELD), J3.18 (SHIELD), R3.2, R10.1, R11.1, R13.1, R14.1, R16.1, R17.1, R18.1, R160.1, U7.41 (GND), Y4.2 (GND), Y4.4 (GND); also elsewhere on the board
MDC_PHY: U7.13 (MDC); also elsewhere on the board
MDIO_PHY: U7.14 (MDIO); also elsewhere on the board
unnamed: J3.14 (LED1A), R20.2
unnamed: J3.16 (LED2A), R19.2
unnamed: C16.2, J3.1 (TRCT3), J3.6 (TRCT2), J3.7 (TRCT4), J3.12 (TRCT1)
unnamed: TP4.1, U7.31 (INTB/PMEB)
unnamed: L1.1, U7.30 (REG_OUT)
unnamed: R3.1, U7.39 (RSET)
unnamed: C4.1, R160.2, U7.36 (XTAL_IN), Y4.1 (X)
unnamed: C3.1, C247.1, U7.37 (XTAL_OUT/EXT_CLK), Y4.3 (X)
PHY_RSTn: U7.12 (PHYRSTB); also elsewhere on the board
REG_1V0: C11.2, C12.2, C13.2, C14.2, C15.2, C17.2, C18.2, L1.2, U7.3 (AVDD10), U7.8 (AVDD10), U7.21 (DVDD10), U7.38 (AVDD10)
RGMII_RXD0: R4.1; also elsewhere on the board
RGMII_RXD1: R5.1; also elsewhere on the board
RGMII_RXD2: R6.1; also elsewhere on the board
RGMII_RXD3: R7.1; also elsewhere on the board
RGMII_RX_CLK: R8.1; also elsewhere on the board
RGMII_RX_DV: R9.1; also elsewhere on the board
RGMII_TXD0: U7.18 (TXD0); also elsewhere on the board
RGMII_TXD1: U7.17 (TXD1); also elsewhere on the board
RGMII_TXD2: U7.16 (TXD2); also elsewhere on the board
RGMII_TXD3: U7.15 (TXD3); also elsewhere on the board
RGMII_TX_CLK: U7.20 (TXC); also elsewhere on the board
RGMII_TX_EN: U7.19 (TXCTL); also elsewhere on the board

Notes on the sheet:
PLLOFF 1'b0: PLL ON
PHY Config
CFG 1'b1: external CFG_LDO[1:0] 2'b00: 3.3V
RXDLY 1'b0: No delay TXDLY 1'b0: No delay
PHYAD[2:0] 3'b001: 0x01

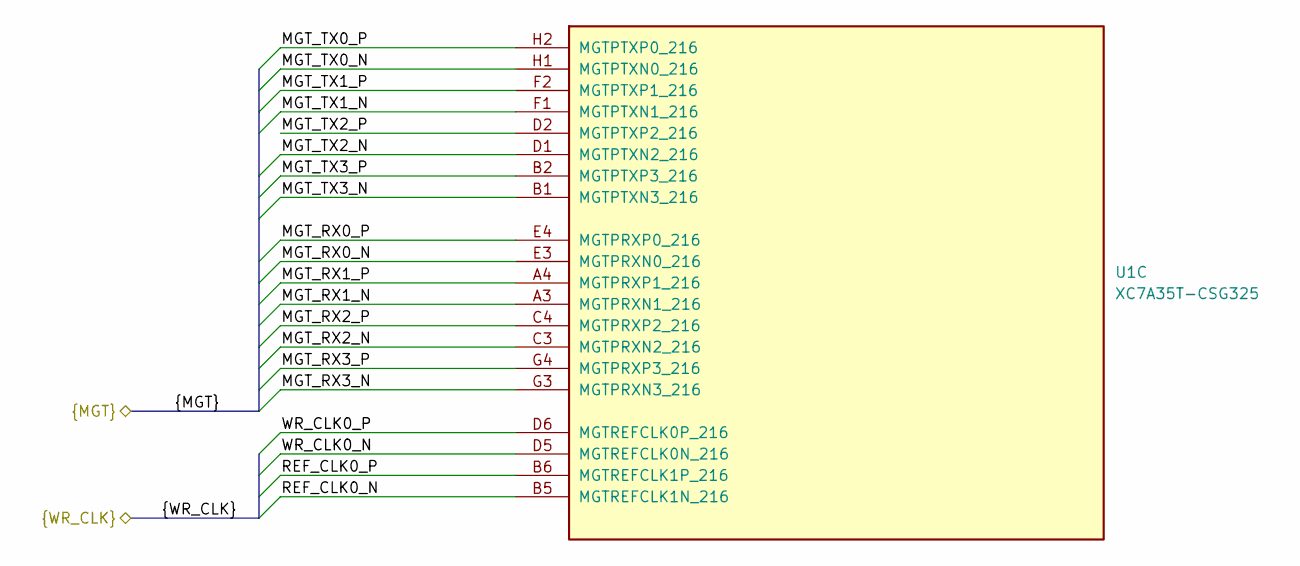
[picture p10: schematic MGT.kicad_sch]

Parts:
U1: XC7A35T-CSG325; Xilinx_CSG325; LCSC C1521749

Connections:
MGT_RX0_N: U1.E3 (MGTPRXN0_216); also elsewhere on the board
MGT_RX0_P: U1.E4 (MGTPRXP0_216); also elsewhere on the board
MGT_RX1_N: U1.A3 (MGTPRXN1_216); also elsewhere on the board
MGT_RX1_P: U1.A4 (MGTPRXP1_216); also elsewhere on the board
MGT_RX2_N: U1.C3 (MGTPRXN2_216); also elsewhere on the board
MGT_RX2_P: U1.C4 (MGTPRXP2_216); also elsewhere on the board
MGT_RX3_N: U1.G3 (MGTPRXN3_216); also elsewhere on the board
MGT_RX3_P: U1.G4 (MGTPRXP3_216); also elsewhere on the board
MGT_TX0_N: U1.H1 (MGTPTXN0_216); also elsewhere on the board
MGT_TX0_P: U1.H2 (MGTPTXP0_216); also elsewhere on the board
MGT_TX1_N: U1.F1 (MGTPTXN1_216); also elsewhere on the board
MGT_TX1_P: U1.F2 (MGTPTXP1_216); also elsewhere on the board
MGT_TX2_N: U1.D1 (MGTPTXN2_216); also elsewhere on the board
MGT_TX2_P: U1.D2 (MGTPTXP2_216); also elsewhere on the board
MGT_TX3_N: U1.B1 (MGTPTXN3_216); also elsewhere on the board
MGT_TX3_P: U1.B2 (MGTPTXP3_216); also elsewhere on the board
REF_CLK0_N: U1.B5 (MGTREFCLK1N_216); also elsewhere on the board
REF_CLK0_P: U1.B6 (MGTREFCLK1P_216); also elsewhere on the board
WR_CLK0_N: U1.D5 (MGTREFCLK0N_216); also elsewhere on the board
WR_CLK0_P: U1.D6 (MGTREFCLK0P_216); also elsewhere on the board

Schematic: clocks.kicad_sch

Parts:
C43, C44, C47, C48, C255, C256, C257, C258, C259, C263, C264: CC0402_1UF_25V_10%_X5R; CAPC1005X55N; Voltage 25V; Tolerance ±10%; Part Number CC0402_1UF_25V_10%_X5R
C49: CC0201_100NF_6.3V_10%_X5R; CAPC0603X33N; Voltage 6.3V; Tolerance ±10%; Part Number CC0201_100NF_6.3V_10%_X5R
C50, C51, C52, C204, C205, C213, C214: CC0402_100NF_50V_10%_X7R; CAPC1005X55N; Voltage 50V; Tolerance ±10%; Part Number CC0402_100NF_50V_10%_X7R
C192, C195, C199, C200: CC0603_22UF_6.3V_20%_X5R; CAPC1709X100N; Voltage 6.3V; Tolerance ±20%; Part Number CC0603_22UF_6.3V_20%_X5R
J16: Conn_Coaxial; SMA_Amphenol_901-144_Vertical
L17, L18: IND0603_MURATA_BLM18SG121TN1D; INDC1608X65N; Tolerance ±25%; Part Number IND0603_MURATA_BLM18SG121TN1D
Q7: BSS138LT1G; SOT95P240X110-3N; Part Number BSS138LT1G
R99, R102: R0402_10K_1%_0.0625W_100PPM; RESC1005X40N; Tolerance ±1%; Part Number R0402_10K_1%_0.0625W_100PPM
R103: R0603_845R_0.1%_0.063W_10PPM; RESC1608X55N; Tolerance ±0.1%; Part Number R0603_845R_0.1%_0.063W_10PPM
R104: R0603_267R_0.1%_0.063W_10PPM; RESC1608X55N; Tolerance ±0.1%; Part Number R0603_267R_0.1%_0.063W_10PPM
R115, R117: R0402_100R_1%_0.1W_100PPM; RESC1005X40N; Voltage 50V; Tolerance ±1%; Part Number R0402_100R_1%_0.1W_100PPM
R159: R0402_40R2_1%_0.0625W_100PPM; RESC1005X40N; Tolerance ±1%; Part Number R0402_40R2_1%_0.0625W_100PPM
U13: SI5340B-D-GM; QFN50P700X700X90-45N-S530; Part Number SI5340B-D-GM
Y1: KC2520Z25.0000C1KX00; Oscillator_SMD_Kyocera_KC2520Z-4Pin_2.5x2.0mm
Y2: XTAL_48MHZ_KYOCERA_CX3225SB48000D0FPJC1; XTAL_KYOCERA_CX3225SB; Part Number XTAL_48MHZ_KYOCERA_CX3225SB48000D0FPJC1

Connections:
25M_CLK_DIS: Q7.1 (G), R102.2; also elsewhere on the board
+1V8: C44.2, C48.2, C263.2, U13.21 (VDD), U13.32 (VDD), U13.39 (VDD), U13.40 (VDD); also elsewhere on the board
+3V3: C49.1, L17.1, R99.2, Y1.4 (VCC); also elsewhere on the board
+3V3_CLEAN: C43.2, C47.2, C199.1, C200.1, C255.2, C256.2, C257.2, C258.2, C259.2, C264.2, L18.2, U13.3 (IN_SEL0), U13.8 (VDDA), U13.9 (VDDA), U13.18 (VDDO0), U13.23 (VDDO1), U13.29 (VDDO2), U13.34 (VDDO3), U13.37 (IN_SEL1)
/Clock-WR/REFCLK0_N: C214.2, U13.35 (~OUT3)
/Clock-WR/REFCLK0_P: C204.2, U13.36 (OUT3)
/Clock-WR/WRCLK0_N: C213.2, U13.19 (~OUT0)
/Clock-WR/WRCLK0_P: C205.2, U13.20 (OUT0)
CLK2: R117.2; also elsewhere on the board
CLK20_VCXO: R115.2; also elsewhere on the board
CLK_25MHZ: R159.2; also elsewhere on the board
GND: C43.1, C44.1, C47.1, C48.1, C49.2, C51.2, C52.2, C192.2, C195.2, C199.2, C200.2, C255.1, C256.1, C257.1, C258.1, C259.1, C263.1, C264.1, J16.2 (Ext), Q7.2 (S), R102.1, U13.26 (VDDS), U13.38 (I2C_SEL), U13.45 (GND), Y1.2 (GND); also elsewhere on the board
GND_CRYSTAL: U13.4 (X1), U13.7 (X2), Y2.2 (GND), Y2.4 (GND)
unnamed: C50.2, R103.2, R104.2
unnamed: C52.1, R103.1
unnamed: C192.1, C195.1, L17.2, L18.1
unnamed: J16.1 (In), R104.1
unnamed: Q7.3 (D), R99.1, Y1.1 (INH)
unnamed: C50.1, U13.43 (IN0)
unnamed: R159.1, U13.25 (OUT1)
unnamed: R115.1, U13.31 (OUT2)
unnamed: U13.5 (XA), Y2.3 (X)
unnamed: U13.6 (XB), Y2.1 (X)
unnamed: C51.1, U13.44 (~IN0)
unnamed: R117.1, Y1.3 (CLK)
REF_CLK0_N: C214.1; also elsewhere on the board
REF_CLK0_P: C204.1; also elsewhere on the board
WR_CLK0_N: C213.1; also elsewhere on the board
WR_CLK0_P: C205.1; also elsewhere on the board
WR_CLK.RSTN: U13.17 (~RST); also elsewhere on the board
WR_CLK.SI5340_IRQ_N: U13.33 (~INTR); also elsewhere on the board
WR_DAC1_SYNC: U13.16 (A0/~CS); also elsewhere on the board
WR_DAC2_SYNC: U13.13 (SDA/SDIO); also elsewhere on the board
WR_DAC_DIN: U13.15 (A1/SDO); also elsewhere on the board
WR_DAC_SCLK: U13.14 (SCLK); also elsewhere on the board

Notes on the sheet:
All outputs LVDS
3.3V LVCMOS

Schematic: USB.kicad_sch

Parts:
C45, C46: CC0805_10UF_25V_10%_X5R; CAPC2012X95N; Voltage 25V; Tolerance ±10%; Part Number CC0805_10UF_25V_10%_X5R
C70, C74, C75, C76, C77, C78, C79, C80, C82, C84, C86, C88: CC0402_100NF_50V_10%_X7R; CAPC1005X55N; Voltage 50V; Tolerance ±10%; Part Number CC0402_100NF_50V_10%_X7R
C71, C72: CC0402_27PF_50V_5%_C0G; CAPC1005X55N; Voltage 50V; Tolerance ±5%; Part Number CC0402_27PF_50V_5%_C0G
C73, C81, C85, C87: CC0402_4.7UF_16V_20%_X5R; CAPC1005X55N; Voltage 16V; Tolerance ±20%; Part Number CC0402_4.7UF_16V_20%_X5R
C83: CC0805_22UF_16V_10%_X5R; CAPC2012X135N; Voltage 16V; Tolerance ±10%; Part Number CC0805_22UF_16V_10%_X5R
D1: PRTR5V0U2X; SOT190P230X110-4N; Voltage 5.5V; Part Number PRTR5V0U2X
J2: USB_C_Receptacle_USB2.0_16P; USB_C_Receptacle_GCT_USB4105-xx-A_16P_TopMnt_Horizontal
JP1, JP2, JP3, JP4: SolderJumper_2_Open; SolderJumper-2_P1.3mm_Open_RoundedPad1.0x1.5mm
L10, L12, L13: IND0402_MURATA_BLM15PX121SN1D; INDC1005X55N; Tolerance ±25%; Part Number IND0402_MURATA_BLM15PX121SN1D
L14: IND_2.2UH_20%_WURTH_WE-PMCI_74479276222C; IND_WURTH_WE-PMCI_0806LR; Tolerance ±20%; Part Number IND_2.2UH_20%_WURTH_WE-PMCI_74479276222C
Q5: DMP3013SFV; Diodes_PowerDI3333-8
R74, R83: R0402_2K2_1%_0.0625W_100PPM; RESC1005X40N; Tolerance ±1%; Part Number R0402_2K2_1%_0.0625W_100PPM
R75, R76, R77, R81, R183, R184, R192, R193: R0402_10K_1%_0.0625W_100PPM; RESC1005X40N; Tolerance ±1%; Part Number R0402_10K_1%_0.0625W_100PPM
R78: R0402_12K_1%_0.0625W_100PPM; RESC1005X40N; Tolerance ±1%; Part Number R0402_12K_1%_0.0625W_100PPM
R79: R0402_4K7_1%_0.0625W_100PPM; RESC1005X40N; Tolerance ±1%; Part Number R0402_4K7_1%_0.0625W_100PPM
R80, R82: R0402_100K_1%_0.0625W_100PPM; RESC1005X40N; Tolerance ±1%; Part Number R0402_100K_1%_0.0625W_100PPM
R194, R195: R0402_22R_1%_0.0625W_100PPM; RESC1005X40N; Tolerance ±1%; Part Number R0402_22R_1%_0.0625W_100PPM
TP1: TestPoint; TestPoint_THTPad_D1.5mm_Drill0.7mm
U8: TLV62565DBV; SOT95P280X145-5N; Part Number TLV62565DBV
U12: HUSB238; SON50P300X300X80-11N-R160X240; MANUFACTURER_PART_NUMBER HUSB238; MOUSER PART NUMBER *
U21: FT2232HQ; QFN50P900X900X100-65N-S445; Part Number FT2232HQ
U22: 93C46B-I_SN; SOIC127P600X175-8N; Part Number 93C46B-I_SN
Y5: XTAL_12MHZ_TXC_7A-12.000MAAJ-T; XTAL_TXC_7A; Part Number XTAL_12MHZ_TXC_7A-12.000MAAJ-T

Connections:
1V8USB: C73.1, C78.2, C79.2, C80.2, U21.12 (VCORE), U21.37 (VCORE), U21.49 (VREGOUT), U21.64 (VCORE)
+3V3: C74.2, C75.2, C76.2, C77.2, U21.20 (VCCIO), U21.31 (VCCIO), U21.42 (VCCIO), U21.56 (VCCIO); also elsewhere on the board
+3V3_USB: C70.2, C82.2, C83.2, C84.1, L10.1, L13.1, L14.2, R75.1, R76.2, R77.2, R79.2, R81.2, TP1.1, U21.50 (VREGIN), U22.8 (VCC)
/USB/CC1: J2.A5 (CC1), U12.4 (CC1)
/USB/CC2: J2.B5 (CC2), U12.5 (CC2)
/USB/USB_N: D1.3 (I/O2), J2.A7 (D-), J2.B7 (D-), U12.3 (D-), U21.7 (DM)
/USB/USB_P: D1.2 (I/O1), J2.A6 (D+), J2.B6 (D+), U12.2 (D+), U21.8 (DP)
GND: C45.1, C46.1, C70.1, C71.2, C72.2, C73.2, C74.1, C75.1, C76.1, C77.1, C78.1, C79.1, C80.1, C81.1, C82.1, C83.1, C84.2, C85.1, C86.1, C87.1, C88.1, D1.1 (GND), J2.A1 (GND), J2.A12 (GND), J2.B1 (GND), J2.B12 (GND), J2.S1 (SHIELD), JP1.2 (B), JP2.2 (B), JP3.2 (B), JP4.2 (B), R78.1, R83.2, U8.2 (GND), U12.11 (GND), U21.1 (GND), U21.5 (GND), U21.10 (AGND), U21.11 (GND), U21.13 (TEST), U21.15 (GND), U21.25 (GND), U21.35 (GND), U21.47 (GND), U21.51 (GND), U21.65 (GND), U22.5 (VSS); also elsewhere on the board
I2C_SCL: U12.7 (SCL); also elsewhere on the board
I2C_SDA: U12.6 (SDA); also elsewhere on the board
JTAG_TCK: U21.16 (ADBUS0); also elsewhere on the board
JTAG_TDI: U21.17 (ADBUS1); also elsewhere on the board
JTAG_TDO: U21.18 (ADBUS2); also elsewhere on the board
JTAG_TMS: U21.19 (ADBUS3); also elsewhere on the board
unnamed: JP1.1 (A), R183.1, U12.8 (VSET)
unnamed: JP2.1 (A), R183.2
unnamed: JP3.1 (A), R184.1, U12.9 (ISET)
unnamed: JP4.1 (A), R184.2
unnamed: Q5.4 (G), R80.2, R82.2, R192.2, R193.2
unnamed: C81.2, L12.2, U8.1 (EN), U8.4 (VIN)
unnamed: R81.1, R83.1, U8.5 (FB)
unnamed: L14.1, U8.3 (SW)
unnamed: R192.1, R193.1, U12.10 (GATE)
unnamed: R194.1, R195.1, U12.1 (VIN)
unnamed: R77.1, U21.62 (EECLK), U22.2 (CLK)
unnamed: R76.1, U21.63 (EECS), U22.1 (CS)
unnamed: R74.2, U21.61 (EEDATA), U22.3 (DI)
unnamed: C72.1, U21.2 (OSCI), Y5.2 (OSC2)
unnamed: C71.1, U21.3 (OSCO), Y5.1 (OSC1)
unnamed: R78.2, U21.6 (REF)
unnamed: R79.1, U21.14 (RESET#)
unnamed: C85.2, C86.2, L10.2, U21.4 (VPHY)
unnamed: C87.2, C88.2, L13.2, U21.9 (VPLL)
unnamed: R74.1, R75.2, U22.4 (DO)
RTS: U21.40 (BDBUS2); also elsewhere on the board
RX: U21.39 (BDBUS1); also elsewhere on the board
TX: U21.38 (BDBUS0); also elsewhere on the board
VCC_USB: C45.2, C46.2, Q5.5 (D); also elsewhere on the board
VUSB: D1.4 (VCC), J2.A4 (VBUS), J2.A9 (VBUS), J2.B4 (VBUS), J2.B9 (VBUS), L12.1, Q5.1 (S), Q5.2 (S), Q5.3 (S), R80.1, R82.1, R194.2, R195.2

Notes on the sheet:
12V

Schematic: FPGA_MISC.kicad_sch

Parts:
C146, C153: CC0201_470NF_4V_20%_X5R; CAPC0603X33N; Voltage 4V; Tolerance ±20%; Part Number CC0201_470NF_4V_20%_X5R
C150: CC0201_47NF_6.3V_10%_X5R; CAPC0603X33N; Voltage 6.3V; Tolerance ±10%; Part Number CC0201_47NF_6.3V_10%_X5R
C151, C152: CC0402_10UF_6.3V_20%_X5R; CAPC1005X70N; Voltage 6.3V; Tolerance ±10%; Part Number CC0402_10UF_6.3V_20%_X5R
C154: CC0201_100NF_6.3V_10%_X5R; CAPC0603X33N; Voltage 6.3V; Tolerance ±10%; Part Number CC0201_100NF_6.3V_10%_X5R
L11: IND0603_MURATA_BLM18AG601SN1; INDC1608X95N; Tolerance ±25%; Part Number IND0603_MURATA_BLM18AG601SN1
L15: IND0805_TDK_MLZ2012M150WT000; INDC2013X145N; Tolerance ±20%; Part Number IND0805_TDK_MLZ2012M150WT000
LD5: LED_KINGBRIGHT_KPH-1608CGCK; Part Number LED_KINGBRIGHT_KPH-1608CGCK
Q3: BSS138LT1G; SOT95P240X110-3N; Part Number BSS138LT1G
R85, R86, R87, R161: R0402_4K7_1%_0.0625W_100PPM; RESC1005X40N; Tolerance ±1%; Part Number R0402_4K7_1%_0.0625W_100PPM
R88, R89, R90: R0402_1K_1%_0.0625W_100PPM; RESC1005X40N; Tolerance ±1%; Part Number R0402_1K_1%_0.0625W_100PPM
SW1: SW_DIP_x01; SW_OMRON_A6SN-1101
U1: XC7A35T-CSG325; Xilinx_CSG325
U9: REF3012; SOT-23
U27: S25FL128SAGMFI001; SOIC127P1030X265-16N; Part Number S25FL128SAGMFI001

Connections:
+3V3: C146.2, C150.2, L15.1, R85.2, R86.2, R87.2, R88.2, R161.2, U1.E10 (VCCO_0), U1.R10 (VCCO_0), U27.2 (VCC), U27.14 (VIO/RFU); also elsewhere on the board
/FPGA_MISC/CCLK: U1.E8 (CCLK_0), U27.16 (SCK)
/FPGA_MISC/VREF: C151.2, C154.2, U1.L10 (VREFP_0), U9.2 (OUT)
CFG_DIN: U27.8 (SO/IO1); also elsewhere on the board
CFG_FCS: U27.7 (~CS); also elsewhere on the board
CFG_MOSI: U27.15 (SI/IO0); also elsewhere on the board
FPGA_DONE: Q3.1 (G), U1.F12 (DONE_0); also elsewhere on the board
GND: C146.1, C150.1, C152.1, C153.1, L11.1, Q3.2 (S), R89.1, R90.1, SW1.1, U1.M9 (DXN_0), U1.M10 (DXP_0), U27.10 (VSS); also elsewhere on the board
JTAG_TCK: U1.F8 (TCK_0); also elsewhere on the board
JTAG_TDI: U1.T9 (TDI_0); also elsewhere on the board
JTAG_TDO: U1.T8 (TDO_0); also elsewhere on the board
JTAG_TMS: U1.R8 (TMS_0); also elsewhere on the board
unnamed: LD5.2 (A), R161.1
unnamed: LD5.1 (C), Q3.3 (D)
unnamed: R86.1, U1.E12 (CFGBVS_0)
unnamed: R87.1, U1.T10 (INIT_B_0)
unnamed: R88.1, U1.R12 (M0_0)
unnamed: R89.2, U1.R11 (M1_0)
unnamed: R90.2, U1.F13 (M2_0)
unnamed: C152.2, C153.2, L15.2, U9.1 (IN)
unnamed: SW1.2, U27.9 (~WP/IO2)
RST: R85.1, U1.P10 (PROGRAM_B_0); also elsewhere on the board
XADCGND: C151.1, C154.1, L11.2, U1.K9 (VREFN_0), U1.K10 (VP_0), U1.L9 (VN_0), U9.3 (GND); also elsewhere on the board

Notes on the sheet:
FPGA DONE

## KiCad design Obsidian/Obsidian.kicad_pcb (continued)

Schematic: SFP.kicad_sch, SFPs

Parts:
C19, C23, C27, C28, C35, C36, C37, C38: CC0805_22UF_16V_10%_X5R; CAPC2012X135N; Voltage 16V; Tolerance ±10%; Part Number CC0805_22UF_16V_10%_X5R
C20, C21, C22, C24, C25, C26, C29, C30, C31, C32, C33, C34, C39, C40, C41, C42, C220, C221, C222: CC0402_100NF_50V_10%_X7R; CAPC1005X55N; Voltage 50V; Tolerance ±10%; Part Number CC0402_100NF_50V_10%_X7R
J1, J11, J12, J13: TYCO_1888247-1; Part Number TYCO_1888247-1
J8, J9: 2180739-1; TE_2180739-1
L2, L3, L4, L5, L6, L7, L8, L9: 4.7 uH; L_1008_2520Metric
R21, R22, R23, R24, R25, R26, R27, R28, R29, R30, R31, R32, R33, R34, R35, R36, R37, R38, R39, R40, R41, R42, R43, R44, R45, R46, R47, R48, R122: R0402_4K7_1%_0.0625W_100PPM; RESC1005X40N; Tolerance ±1%; Part Number R0402_4K7_1%_0.0625W_100PPM
R164, R165, R166, R170, R171, R172, R175: R0402_100K_1%_0.0625W_100PPM; RESC1005X40N; Tolerance ±1%; Part Number R0402_100K_1%_0.0625W_100PPM
U17, U19: TCA9535RTWR; QFN50P400X400X80-25N-S245; 5V TOLERANT I/O Yes; PARTNUMBER TCA9535RTWR
U26: PCA9546ARGV; QFN65P400X400X100-17N-S225; Part Number PCA9546ARGV

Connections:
25M_CLK_DIS: U19.16; also elsewhere on the board
+3V3: C21.2, C22.2, C25.2, C26.2, C31.2, C32.2, C33.2, C34.2, C220.2, C221.2, C222.2, L2.1, L3.1, L4.1, L5.1, L6.1, L7.1, L8.1, L9.1, R21.2, R23.2, R24.2, R25.2, R26.2, R27.2, R28.2, R30.2, R31.2, R32.2, R33.2, R34.2, R35.2, R37.2, R39.2, R40.2, R41.2, R42.2, R43.2, R44.2, R45.2, R46.2, R47.2, R48.2, R122.2, R164.1, U17.21 (VCC), U19.18 (A0), U19.21 (VCC), U26.14 (VCC); also elsewhere on the board
/SFP/I2C_SFP0_SCL: J12.5 (SCL), R24.1, U26.3 (SC0)
/SFP/I2C_SFP0_SDA: J12.4 (SDA), R23.1, U26.2 (SD0)
/SFP/I2C_SFP1_SCL: J1.5 (SCL), R31.1, U26.5 (SC1)
/SFP/I2C_SFP1_SDA: J1.4 (SDA), R30.1, U26.4 (SD1)
/SFP/I2C_SFP2_SCL: J11.5 (SCL), R41.1, U26.8 (SC2)
/SFP/I2C_SFP2_SDA: J11.4 (SDA), R39.1, U26.7 (SD2)
/SFP/I2C_SFP3_SCL: J13.5 (SCL), R42.1, U26.10 (SC3)
/SFP/I2C_SFP3_SDA: J13.4 (SDA), R40.1, U26.9 (SD3)
/SFP/RS0: J12.7 (RS0), J12.9 (RS1), R26.1, U17.4 (P03)
/SFP/RS1: J1.7 (RS0), J1.9 (RS1), R33.1, U17.13
/SFP/RS2: J11.7 (RS0), J11.9 (RS1), R45.1, U19.4 (P03)
/SFP/RS3: J13.7 (RS0), J13.9 (RS1), R46.1, U19.13
/SFP/SFP0_DEF0: J12.6 (MOD_ABS), R25.1, U17.3 (P02)
/SFP/SFP0_LOS: J12.8 (LOS), R27.1, U17.5 (P04)
/SFP/SFP0_TX_DIS: J12.3 (TX_DISABLE), R22.2, U17.2 (P01)
/SFP/SFP0_TX_FAULT: J12.2 (TX_FAULT), R21.1, U17.1 (P00)
/SFP/SFP1_DEF0: J1.6 (MOD_ABS), R32.1, U17.12
/SFP/SFP1_LOS: J1.8 (LOS), R34.1, U17.14
/SFP/SFP1_TX_DIS: J1.3 (TX_DISABLE), R29.2, U17.11
/SFP/SFP1_TX_FAULT: J1.2 (TX_FAULT), R28.1, U17.10
/SFP/SFP2_DEF0: J11.6 (MOD_ABS), R43.1, U19.3 (P02)
/SFP/SFP2_LOS: J11.8 (LOS), R47.1, U19.5 (P04)
/SFP/SFP2_TX_DIS: J11.3 (TX_DISABLE), R36.2, U19.2 (P01)
/SFP/SFP2_TX_FAULT: J11.2 (TX_FAULT), R35.1, U19.1 (P00)
/SFP/SFP3_DEF0: J13.6 (MOD_ABS), R44.1, U19.12
/SFP/SFP3_LOS: J13.8 (LOS), R48.1, U19.14
/SFP/SFP3_TX_DIS: J13.3 (TX_DISABLE), R38.2, U19.11
/SFP/SFP3_TX_FAULT: J13.2 (TX_FAULT), R37.1, U19.10
GND: C19.1, C20.1, C21.1, C22.1, C23.1, C24.1, C25.1, C26.1, C27.1, C28.1, C29.1, C30.1, C31.1, C32.1, C33.1, C34.1, C35.1, C36.1, C37.1, C38.1, C39.1, C40.1, C41.1, C42.1, C220.1, C221.1, C222.1, J1.1 (VEET), J1.10 (VEER), J1.11 (VEER), J1.14 (VEER), J1.17 (VEET), J1.20 (VEET), J8.SH1 (CHASSIS_GND1), J8.SH2 (CHASSIS_GND1), J8.SH3 (CHASSIS_GND1), J8.SH4 (CHASSIS_GND1), J8.SH5 (CHASSIS_GND1), J8.SH6 (CHASSIS_GND1), J8.SH7 (CHASSIS_GND1), J8.SH8 (CHASSIS_GND1), J8.SH9 (CHASSIS_GND1), J8.SH10 (CHASSIS_GND1), J8.SH11 (CHASSIS_GND1), J8.SH12 (CHASSIS_GND1), J8.SH13 (CHASSIS_GND1), J8.SH14 (CHASSIS_GND1), J8.SH15 (CHASSIS_GND1), J8.SH16 (CHASSIS_GND2), J8.SH17 (CHASSIS_GND2), J8.SH18 (CHASSIS_GND2), J8.SH19 (CHASSIS_GND2), J8.SH20 (CHASSIS_GND2), J8.SH21 (CHASSIS_GND2), J8.SH22 (CHASSIS_GND2), J8.SH23 (CHASSIS_GND2), J8.SH24 (CHASSIS_GND2), J8.SH25 (CHASSIS_GND2), J9.SH1 (CHASSIS_GND1), J9.SH2 (CHASSIS_GND1), J9.SH3 (CHASSIS_GND1), J9.SH4 (CHASSIS_GND1), J9.SH5 (CHASSIS_GND1), J9.SH6 (CHASSIS_GND1), J9.SH7 (CHASSIS_GND1), J9.SH8 (CHASSIS_GND1), J9.SH9 (CHASSIS_GND1), J9.SH10 (CHASSIS_GND1), J9.SH11 (CHASSIS_GND1), J9.SH12 (CHASSIS_GND1), J9.SH13 (CHASSIS_GND1), J9.SH14 (CHASSIS_GND1), J9.SH15 (CHASSIS_GND1), J9.SH16 (CHASSIS_GND2), J9.SH17 (CHASSIS_GND2), J9.SH18 (CHASSIS_GND2), J9.SH19 (CHASSIS_GND2), J9.SH20 (CHASSIS_GND2), J9.SH21 (CHASSIS_GND2), J9.SH22 (CHASSIS_GND2), J9.SH23 (CHASSIS_GND2), J9.SH24 (CHASSIS_GND2), J9.SH25 (CHASSIS_GND2), J11.1 (VEET), J11.10 (VEER), J11.11 (VEER), J11.14 (VEER), J11.17 (VEET), J11.20 (VEET), J12.1 (VEET), J12.10 (VEER), J12.11 (VEER), J12.14 (VEER), J12.17 (VEET), J12.20 (VEET), J13.1 (VEET), J13.10 (VEER), J13.11 (VEER), J13.14 (VEER), J13.17 (VEET), J13.20 (VEET), R22.1, R29.1, R36.1, R38.1, R165.1, R166.1, R170.1, R171.1, R172.1, R175.1, U17.9 (GND), U17.18 (A0), U17.23 (A1), U17.24 (A2), U17.25 (EP), U19.9 (GND), U19.23 (A1), U19.24 (A2), U19.25 (EP), U26.6 (GND), U26.11 (A2), U26.15 (A0), U26.16 (A1); also elsewhere on the board
I2C_SCL: U17.19 (SCL), U19.19 (SCL), U26.12 (SCL); also elsewhere on the board
I2C_SDA: U17.20 (SDA), U19.20 (SDA), U26.13 (SDA); also elsewhere on the board
LED0: U17.16; also elsewhere on the board
LED1: U17.17; also elsewhere on the board
MGT_RX0_N: J12.12 (RD-); also elsewhere on the board
MGT_RX0_P: J12.13 (RD+); also elsewhere on the board
MGT_RX1_N: J1.12 (RD-); also elsewhere on the board
MGT_RX1_P: J1.13 (RD+); also elsewhere on the board
MGT_RX2_N: J11.12 (RD-); also elsewhere on the board
MGT_RX2_P: J11.13 (RD+); also elsewhere on the board
MGT_RX3_N: J13.12 (RD-); also elsewhere on the board
MGT_RX3_P: J13.13 (RD+); also elsewhere on the board
MGT_TX0_N: J12.19 (TD-); also elsewhere on the board
MGT_TX0_P: J12.18 (TD+); also elsewhere on the board
MGT_TX1_N: J1.19 (TD-); also elsewhere on the board
MGT_TX1_P: J1.18 (TD+); also elsewhere on the board
MGT_TX2_N: J11.19 (TD-); also elsewhere on the board
MGT_TX2_P: J11.18 (TD+); also elsewhere on the board
MGT_TX3_N: J13.19 (TD-); also elsewhere on the board
MGT_TX3_P: J13.18 (TD+); also elsewhere on the board
unnamed: C27.2, C29.2, J1.15 (VCCR), L4.2
unnamed: C28.2, C30.2, J1.16 (VCCT), L5.2
unnamed: C35.2, C39.2, J11.15 (VCCR), L6.2
unnamed: C36.2, C40.2, J11.16 (VCCT), L7.2
unnamed: C19.2, C20.2, J12.15 (VCCR), L2.2
unnamed: C23.2, C24.2, J12.16 (VCCT), L3.2
unnamed: C37.2, C41.2, J13.15 (VCCR), L8.2
unnamed: C38.2, C42.2, J13.16 (VCCT), L9.2
unnamed: R164.2, U17.6 (P05)
unnamed: R165.2, U17.7 (P06)
unnamed: R166.2, U17.8 (P07)
unnamed: R170.2, U19.6 (P05)
unnamed: R171.2, U19.7 (P06)
unnamed: R172.2, U19.8 (P07)
unnamed: R175.2, U19.17
RST: R122.1, U26.1 (~RESET); also elsewhere on the board
WR_CLK.RSTN: U19.15; also elsewhere on the board
WR_CLK.SI5340_IRQ_N: U17.15; also elsewhere on the board

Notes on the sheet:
Revison: ${rev} 000 - rev: 1.0.0 001 - rev: ${rev} xx0 - R164 - P05 x0x - R165 - P06 0xx - R166 - P07
Board revision code

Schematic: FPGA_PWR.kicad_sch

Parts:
C89, C90, C91, C92, C93, C94, C95, C96, C113, C114, C115, C116, C120, C155: CC0201_470NF_4V_20%_X5R; CAPC0603X33N; Voltage 4V; Tolerance ±20%; Part Number CC0201_470NF_4V_20%_X5R; LCSC C85926
C97, C98, C99, C100, C101, C102, C112, C121: CC0201_47NF_6.3V_10%_X5R; CAPC0603X33N; Voltage 6.3V; Tolerance ±10%; Part Number CC0201_47NF_6.3V_10%_X5R; LCSC C565524
C103, C104, C105, C106, C107, C108, C117, C118, C156, C161, C162, C167, C168: CC0402_4.7UF_16V_20%_X5R; CAPC1005X55N; Voltage 16V; Tolerance ±20%; Part Number CC0402_4.7UF_16V_20%_X5R; LCSC C318563
C109, C110, C111, C119, C122: CC0805_100UF_6.3V_20%_X5R; CAPC2012X145N; Voltage 6.3V; Tolerance ±20%; Part Number CC0805_100UF_6.3V_20%_X5R; LCSC C141660
C157, C158, C159, C160, C163, C164, C165, C166, C169: CC0201_100NF_6.3V_10%_X5R; CAPC0603X33N; Voltage 6.3V; Tolerance ±10%; Part Number CC0201_100NF_6.3V_10%_X5R; LCSC C190187
L16: IND0402_MURATA_BLM15HB221SN1; INDC1005X55N; Tolerance ±25%; Part Number IND0402_MURATA_BLM15HB221SN1; LCSC C88966
R114: R0402_100R_1%_0.1W_100PPM; RESC1005X40N; Voltage 50V; Tolerance ±1%; Part Number R0402_100R_1%_0.1W_100PPM; LCSC C413063
U1: XC7A35T-CSG325; Xilinx_CSG325; LCSC C1521749

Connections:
+1V0: C89.2, C90.2, C91.2, C92.2, C93.2, C94.2, C95.2, C96.2, C97.2, C98.2, C99.2, C100.2, C101.2, C102.2, C103.2, C104.2, C105.2, C106.2, C107.2, C108.2, C109.2, C110.2, C111.2, C120.2, C121.2, C122.2, C157.2, C158.2, C159.2, C160.2, C161.2, C162.2, U1.B4 (MGTAVCC), U1.C5 (MGTAVCC), U1.E5 (MGTAVCC), U1.F5 (MGTAVCC), U1.F7 (VCCINT), U1.F9 (VCCINT), U1.F11 (VCCBRAM), U1.G8 (VCCINT), U1.G10 (VCCBRAM), U1.H7 (VCCINT), U1.H9 (VCCINT), U1.H11 (VCCBRAM), U1.J8 (VCCINT), U1.J12 (VCCINT), U1.K7 (VCCINT), U1.K11 (VCCINT), U1.L8 (VCCINT), U1.L12 (VCCINT), U1.M7 (VCCINT), U1.M11 (VCCINT), U1.N8 (VCCINT), U1.N10 (VCCINT), U1.N12 (VCCINT), U1.P9 (VCCINT), U1.P11 (VCCINT); also elsewhere on the board
+1V2: C163.2, C164.2, C165.2, C166.2, C167.2, C168.2, C169.2, R114.2, U1.A2 (MGTAVTT), U1.C1 (MGTAVTT), U1.E1 (MGTAVTT), U1.F3 (MGTAVTT), U1.G2 (MGTAVTT); also elsewhere on the board
+1V8: C112.2, C113.2, C114.2, C115.2, C116.2, C117.2, C118.2, C119.2, C156.2, L16.1, U1.E11 (VCCBATT_0), U1.G12 (VCCAUX), U1.H13 (VCCAUX), U1.K13 (VCCAUX), U1.M13 (VCCAUX), U1.P13 (VCCAUX); also elsewhere on the board
GND: C89.1, C90.1, C91.1, C92.1, C93.1, C94.1, C95.1, C96.1, C97.1, C98.1, C99.1, C100.1, C101.1, C102.1, C103.1, C104.1, C105.1, C106.1, C107.1, C108.1, C109.1, C110.1, C111.1, C112.1, C113.1, C114.1, C115.1, C116.1, C117.1, C118.1, C119.1, C120.1, C121.1, C122.1, C155.1, C156.1, C157.1, C158.1, C159.1, C160.1, C161.1, C162.1, C163.1, C164.1, C165.1, C166.1, C167.1, C168.1, C169.1, U1.A1 (GND), U1.A5 (GND), U1.A7 (GND), U1.A8 (GND), U1.A11 (GND), U1.A18 (GND), U1.B3 (GND), U1.B7 (GND), U1.B8 (GND), U1.B18 (GND), U1.C2 (GND), U1.C6 (GND), U1.C7 (GND), U1.C15 (GND), U1.D3 (GND), U1.D4 (GND), U1.D7 (GND), U1.D12 (GND), U1.E2 (GND), U1.E6 (GND), U1.E7 (GND), U1.E9 (GND), U1.F4 (GND), U1.F6 (GND), U1.F10 (GND), U1.F16 (GND), U1.G1 (GND), U1.G5 (GND), U1.G6 (GND), U1.G7 (GND), U1.G9 (GND), U1.G11 (GND), U1.G13 (GND), U1.H3 (GND), U1.H4 (GND), U1.H5 (GND), U1.H6 (GND), U1.H8 (GND), U1.H10 (GND), U1.H12 (GND), U1.J1 (GND), U1.J2 (GND), U1.J3 (GND), U1.J7 (GND), U1.J11 (GND), U1.J13 (GND), U1.J17 (GND), U1.K4 (GND), U1.K8 (GND), U1.K12 (GND), U1.K14 (GND), U1.L1 (GND), U1.L7 (GND), U1.L11 (GND), U1.L13 (GND), U1.M8 (GND), U1.M12 (GND), U1.M18 (GND), U1.N5 (GND), U1.N7 (GND), U1.N9 (GND), U1.N11 (GND), U1.N13 (GND), U1.N15 (GND), U1.P2 (GND), U1.P8 (GND), U1.P12 (GND), U1.R9 (GND), U1.T6 (GND), U1.T16 (GND), U1.U3 (GND), U1.U13 (GND), U1.V1 (GND), U1.V10 (GND), U1.V18 (GND); also elsewhere on the board
unnamed: R114.1, U1.A6 (MGTRREF_216)
unnamed: C155.2, L16.2, U1.J10 (VCCADC_0)
XADCGND: U1.J9 (GNDADC_0); also elsewhere on the board

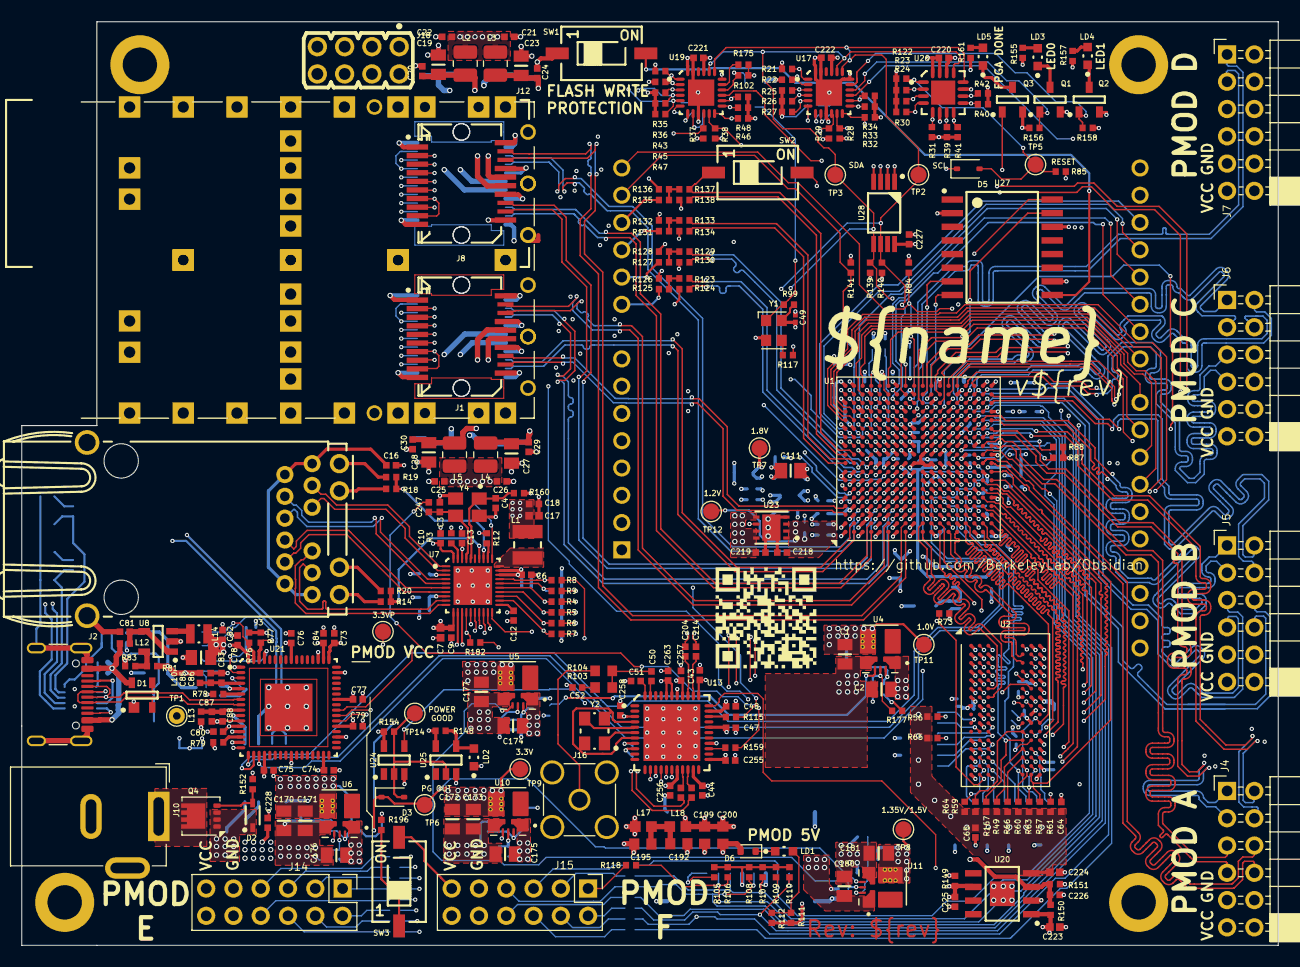
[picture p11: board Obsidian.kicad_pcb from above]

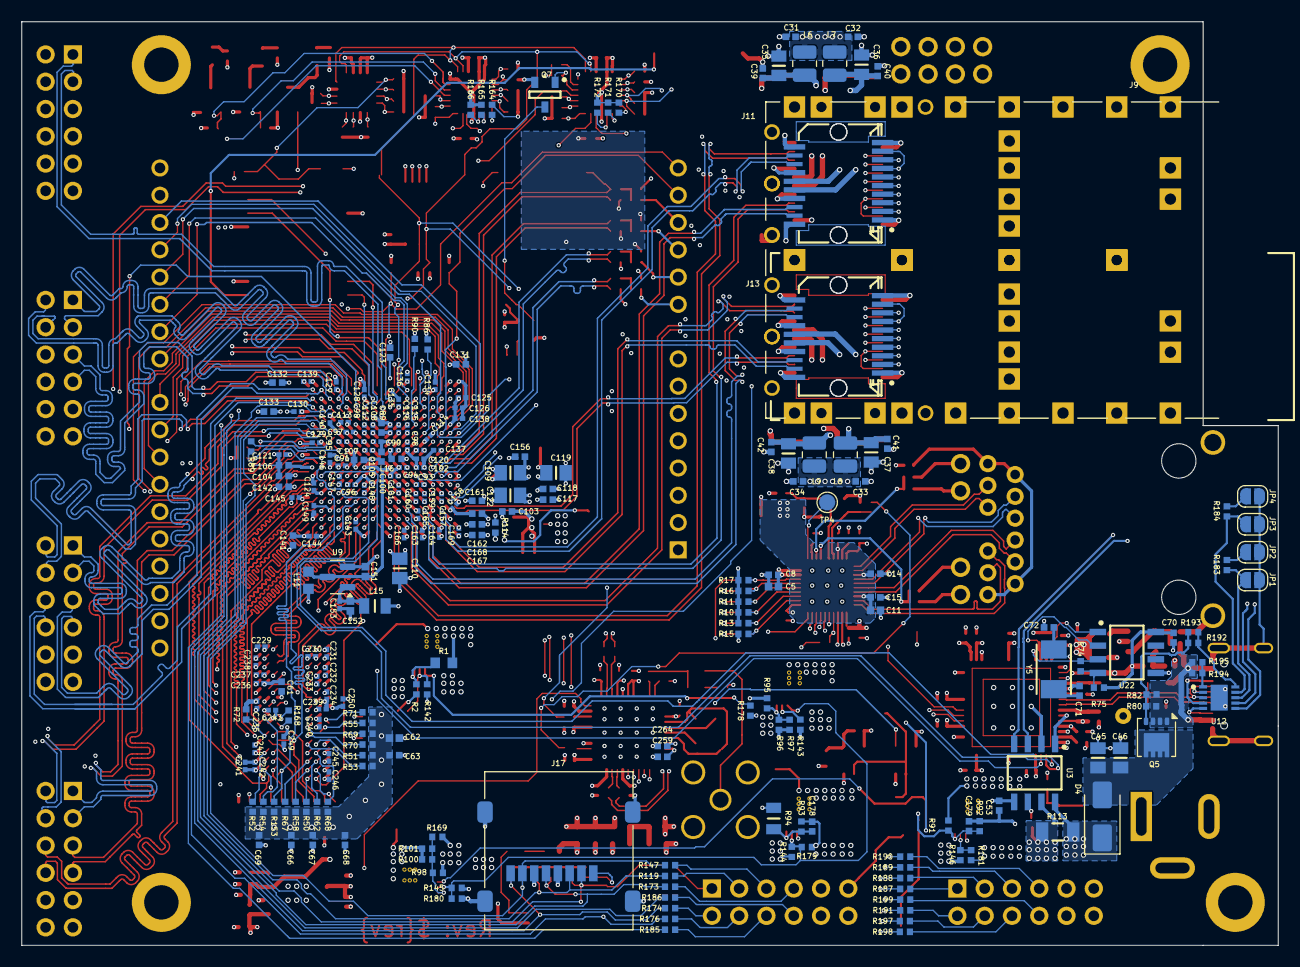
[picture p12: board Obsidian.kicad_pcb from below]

Board: 8 copper layers, 117.0 x 86.0 mm, 521 parts (238 on the bottom side), 370 nets.

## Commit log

2025-03-27 components placement and PCB routing
    [DDR.kicad_sch, Ethernet.kicad_sch, FPGA.kicad_sch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]
2025-04-17 PCB done
    [Ethernet.kicad_sch, FPGA.kicad_sch, FPGA_MISC.kicad_sch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]
2025-04-18 corrected location of pmod connectors
2025-04-25 connected more address lines to DDR, new board name
    [DDR.kicad_sch, Ethernet.kicad_sch, FPGA.kicad_sch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]
2025-05-22 ready for the final review
    [Arduino.kicad_sch, FPGA.kicad_sch, FPGA_MISC.kicad_sch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]
2025-10-08 license.txt: switch from CERN-OHL-P-2.0 to CERN-OHL-W-2.0 license
2025-12-30 Removing unnecessary components for the interface. Adding SPIN schematic and footprint
    [Arduino.kicad_sch, DDR.kicad_sch, Ethernet.kicad_sch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]
2025-12-30 adding SPIN, and 5V power for the MCU
    [FPGA.kicad_sch, Power.kicad_sch, SPIN.kicad_sch]
2026-01-23 update with available components on LCSC
    [Arduino.kicad_sch, DDR.kicad_sch, Ethernet.kicad_sch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]
2026-01-26 adding wago
    [Obsidian.kicad_sch, Power.kicad_sch, untitled.kicad_sch]
2026-01-27 replacing global label with hierarchical label
    [Arduino.kicad_sch, DDR.kicad_sch, Ethernet.kicad_sch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]
2026-01-27 correcting SFP cages footprint
2026-01-27 adding new netclass for DDR memory
    [DDR.kicad_sch]
2026-01-29 Adding symbol library
    [Arduino.kicad_sch, DDR.kicad_sch, Ethernet.kicad_sch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]
2026-01-30 Correct Schematic errors
    [Arduino.kicad_sch, DDR.kicad_sch, Ethernet.kicad_sch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]
2026-01-30 correcting mismatch in TX/RX of UART
    [FPGA.kicad_sch, FPGA_MISC.kicad_sch, USB.kicad_sch]
2026-02-09 adding 3D files, 3D model of twist, and correct DRC
    [Arduino.kicad_sch, FPGA_MISC.kicad_sch, Obsidian.kicad_sch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]
2026-02-10 update pcb
2026-02-10 Changed layout in a way TWIST and Obsidian are aligned properly.
    [PMODs.kicad_sch]
2026-02-10 adding a standoff 30mm for TWIST mechanical connection
2026-02-11 revison v1.1.0 ready to review
    [Arduino.kicad_sch, FPGA.kicad_sch, FPGA_MISC.kicad_sch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]
2026-03-12 minor changes
    [Arduino.kicad_sch, DDR.kicad_sch, Ethernet.kicad_sch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]
2026-03-12 new 3D render
    [Arduino.kicad_sch, DDR.kicad_sch, Ethernet.kicad_sch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]
2026-03-23 new LBL logo
    [Obsidian-B_Adhesive.gbr, Obsidian-B_Courtyard.gbr, Obsidian-B_Cu.gbr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]
2026-04-07 new font; removed clk gen; added resistors for 2 PMODs
    [Obsidian-B_Adhesive.gbr, Obsidian-B_Courtyard.gbr, Obsidian-B_Cu.gbr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]
2026-04-07 removed Fabrication folder
    [Obsidian-B_Adhesive.gbr, Obsidian-B_Courtyard.gbr, Obsidian-B_Cu.gbr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]
2026-05-04 ready to manufacture
    [FPGA_MISC.kicad_sch, Obsidian.kicad_pcb, PMODs.kicad_sch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]

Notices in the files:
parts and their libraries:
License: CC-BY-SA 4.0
